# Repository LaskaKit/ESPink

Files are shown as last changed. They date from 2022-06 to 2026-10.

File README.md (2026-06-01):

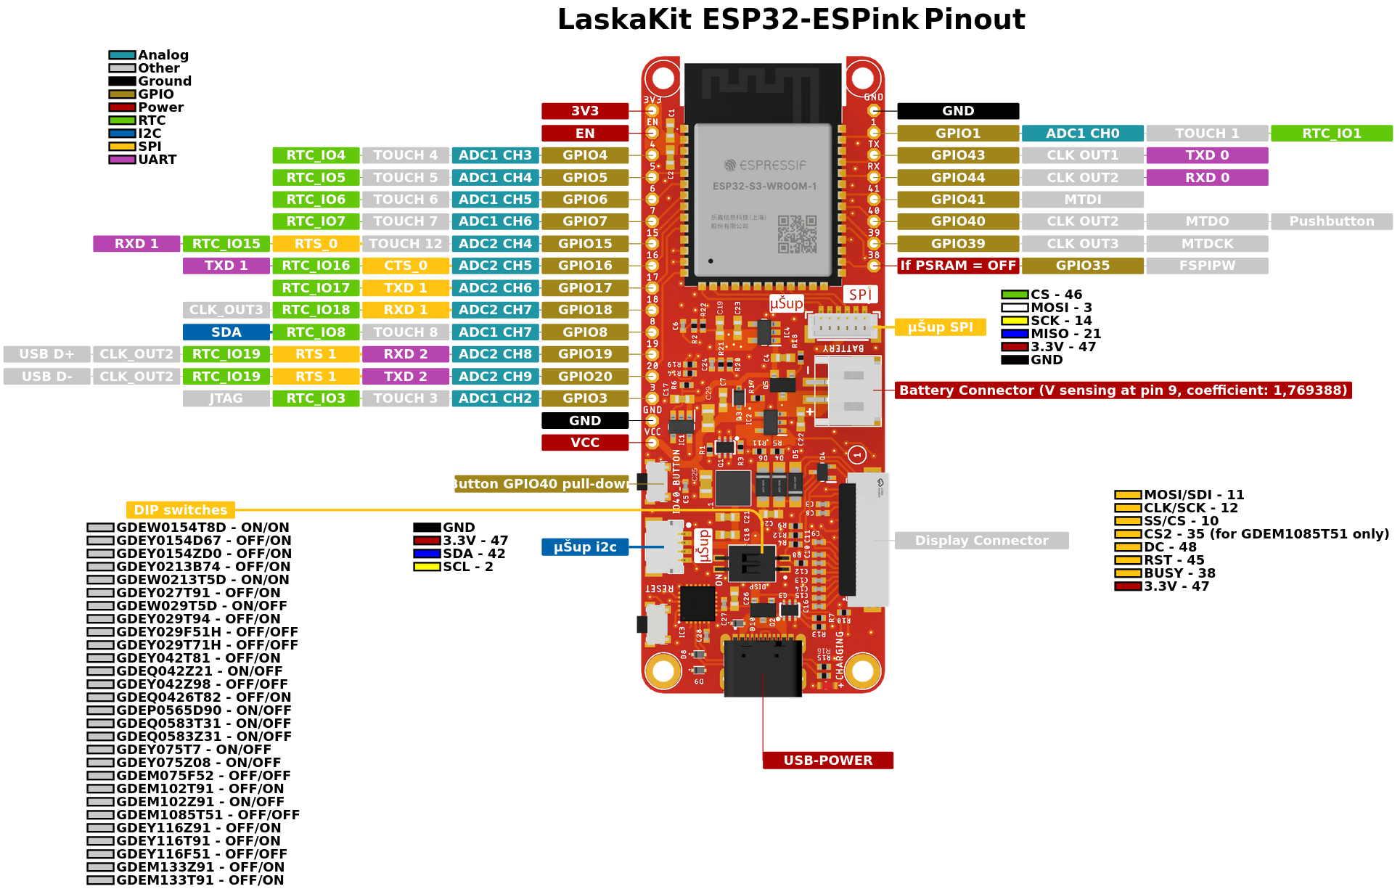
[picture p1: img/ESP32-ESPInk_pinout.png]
ESPink top


# ESPink - versatile and low power board with ESP32 for ePaper/eInk

[ePaper displays](https://www.laskakit.cz/e-ink/) are becoming more and more popular mainly thanks to their low power consumption and wide viewing angle. 
But which board you should use to control your E-Paper display? We designed a board to answer this very question: The ESPink, a small board focused on the lowest possible power consumption and with plenty of memory for large, complicated graphics. 
The ESPink is based on ESP32, one of the most popular and widely accepted development boards in the world. 

What makes this board so special? First of all, a dedicated connect onnector for connection of an ePaper/eInk display. EPaper displays consume very little power, but it is drawing current during sleep (a few uA). To achieve the lowest current, we added a transistor between power and input of ePaper. Thanks to this, the current through ePaper during the sleep is zero. This same tranzistor is also used to switch the µŠup I2C and µŠup SPI power.

One more feature is the built-in programmer, where we used really low power programmer.

The board is powered from [lipol battery](https://www.laskakit.cz/baterie-a-akumulatory/) which is chargered from USB-C, no longer micro USB. As is standard with our boards, we've included a voltage divider (coef. 1.769388) which allows you to measure the voltage of the connected battery.

The connection of sensors is simple and secure thanks to our I2C μŠup connector, which includes a mechanical lock and a pinout compatible with all sensors and boards made by laskakit.cz, in addition to Adafruit STEMMA and Sparkfun QWIIC boards.  
Examples of boards with the μŠup connector are [LaskaKit SHT40 Sensor of temperature and humidity](https://www.laskakit.cz/laskakit-sht40-senzor-teploty-a-vlhkosti-vzduchu/) and  [LaskaKit SCD41 Sensor CO2, temperature and humidity ](https://www.laskakit.cz/laskakit-scd41-senzor-co2--teploty-a-vlhkosti-vzduchu/).
We also added an SPI μŠup connector for adding more data-hungry devices, such as SD card readers. 

The ESP32 has a lot of available GPIO pins which we didn't use, which are accesible via solder pads, allowing you to connect any and all modules you can think of.

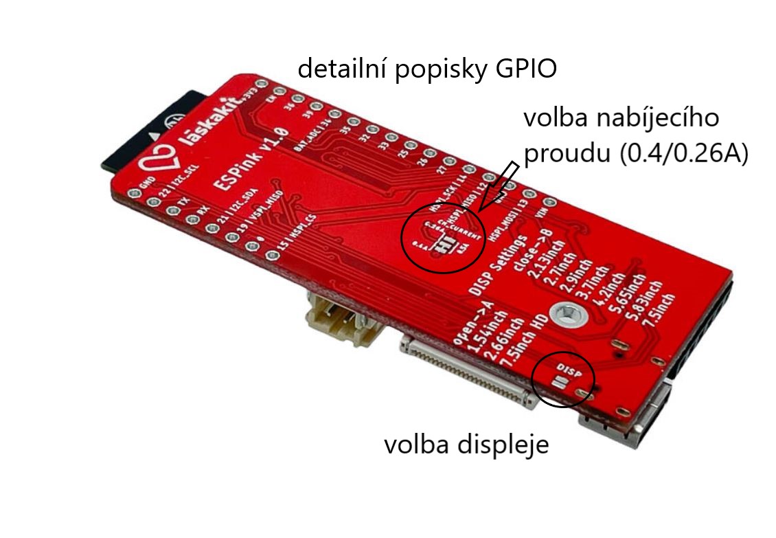
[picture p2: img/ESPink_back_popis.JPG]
ESPink top


The ESPink was precisly designed for low power, but also the labeled GPIO what we used on board. On the bottom side is solder bridge, which defines the charging current. By default it is set 400 mA, but you can choose 260 mA. Just cut the this track and put a drop of solder on the oposite side of solder bridge.

ESPink is available on https://www.laskakit.cz/laskakit-espink-esp32-e-paper-pcb-antenna/
We prepared example codes available here: https://github.com/LaskaKit/ESPink/tree/main/SW

## Pinout
### Board

| Function | Board Version 2.7 | Board Version 3.5 |
| --- |:---:|:---:|
| MOSI/SDI | 23 | 11 |
| CLK/SCK | 5 | 10 |
| CS2 | - | 35 |
| DC | 17 | 48 |
| RST | 16 | 45 |
| BUSY | 4 | 38 |
| Voltage divider | 34 | 9 |

### µŠup I2C

| Function | Board Version 2.7 | Board Version 3.5 |
| --- |:---:|:---:|
|SDA|21|42|
|SCL|22|2|

### µŠup SPI

| Function | Board Version 2.7 | Board Version 3.5 |
| --- |:---:|:---:|
|MOSI/SDI|13|3|
|MISO/SDO|12|21|
|SCK|14|14|
|CS|15|46|

### DIP Switch positions
| Display Name | Positions |
| --- | --- |
| GDEW0154T8D  | ON/ON |
| GDEY0154D67  | OFF/ON |
| GDEY0154ZD0  | OFF/ON |
| GDEY0213B74  | OFF/ON |
| GDEW0213T5D  | ON/ON |
| GDEY027T91 | OFF/ON |
| GDEW029T5D | OFF/OFF |
| GDEY029T94 | OFF/OFF |
| GDEY029F51H  | OFF/ON |
| GDEY029T71H  | ON/OFF |
| GDEY042T81 | OFF/ON |
| GDEQ042Z21 | ON/OFF |
| GDEY042Z98 | OFF/OFF |
| GDEQ0426T82  | OFF/ON |
| GDEP0565D90  | ON/OFF |
| GDEQ0583T31  | ON/OFF |  
| GDEQ0583Z31  | ON/OFF |
| GDEY075T7 | ON/OFF |
| GDEY075Z08 | ON/OFF |
| GDEM075F52 | OFF/OFF |
| GDEM102T91 | OFF/ON |
| GDEM102Z91 | OFF/ON |
| GDEM1085T51  | OFF/OFF |
| GDEY116Z91 | OFF/ON |
| GDEY116T91 | OFF/ON |
| GDEY116F51 | OFF/OFF |
| GDEM133Z91 | OFF/ON |
| GDEM133T91 | OFF/ON |

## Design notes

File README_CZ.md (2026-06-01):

ESPink top

# ESPink - univerzální a velmi úsporná deska s ESP32 pro ePaper

[ePaper displeje](https://www.laskakit.cz/e-ink/) nabírají neuřitelné popularity a není divu. Především velmi nízký odběr a široký pozorovací úhel dělá ePaper tak populárním. 
Ale čím tento displej řídit? Proto jsme navrhli ESPink. Velká paměť, nízký odběr, snadné připojení I2C čidel a velká komunita bastlířů okolo ESP32.

Na desce samozřejmě najdeš konektor pro ePaper displeje. Někdy nazvaný také Eink. Displej sám o sobě je velmi úsporný, ale stejně i mimo fázi přepisu odebírá nějaké ty uA. 
I takovému odběru jsme chtěli zamezit a tak jsme do napájení přidali tranzistor, který spíná nejen napájení E-Paper displeje, ale i µŠup I2C a µŠup SPI.

Nízká spotřeba je dosažena i tím, že jsme použili programátor, který je sám o sobě velmi úsporný a tak jeho osazení na desce nepřinese o mnoho vyšší spotřebu.

Deska může být napájena z [lipol akumulátoru](https://www.laskakit.cz/baterie-a-akumulatory/) a ten je nabíjen z USB-C konektoru. 
Samozřejmě můžeš měřit i napětí na akumulátoru díky integrovanému děliči napětí (koef. 1,769388).

Připojení čidel nebylo nikdy snažší a bezpečnější. Žádná nefungující čidla způsobená přepolováním. Díky našemu I2C μŠup konektoru, který obsahuje i zámek čidla jednoduše připojíš. 
Mezi taková čidla s μŠup konektorem patří [LaskaKit SHT40 Senzor teploty a vlhkosti vzduchu ](https://www.laskakit.cz/laskakit-sht40-senzor-teploty-a-vlhkosti-vzduchu/) nebo  [LaskaKit SCD41 Senzor CO2, teploty a vlhkosti vzduchu ](https://www.laskakit.cz/laskakit-scd41-senzor-co2--teploty-a-vlhkosti-vzduchu/).
Na desce je i SPI μŠup konektor, který může být použit například pro připojení naší desky nazvané microSD reader. 

K dispozici je i spousta GPIO, na které si můžeš zapájet, co budeš potřebovat.

ESPink top

Dali jsme si záležet i na takových detailech, jako jsou například označené GPIO, které deska využívá. Na zadní straně se ještě nachází pájecí most, který určuje nabíjecí proud. 
Ve vychozím nastavení je nastaveno 400mA. Pokud chceš nabíjet 260mA, je nutné proškrábnout most a zapájet jej na druhé straně. 

ESPink najdeš na našem e-shopu https://www.laskakit.cz/laskakit-espink-esp32-e-paper-pcb-antenna/
A několik vzorových kódu i na našem githubu https://github.com/LaskaKit/ESPink/tree/main/SW

## Pinout
### Deska

| Funkce | Verze Desky 2.7 | Verze Desky 3.5 |
| --- |:---:|:---:|
| MOSI/SDI | 23 | 11 |
| CLK/SCK | 5 | 10 |
| CS2 | - | 35 |
| DC | 17 | 48 |
| RST | 16 | 45 |
| BUSY | 4 | 38 |
| Dělič napětí | 34 | 9 |

### µŠup I2C

| Funkce | Verze Desky 2.7 | Verze Desky 3.5 |
| --- |:---:|:---:|
|SDA|21|42|
|SCL|22|2|

### µŠup SPI

| Funkce | Verze Desky 2.7 | Verze Desky 3.5 |
| --- |:---:|:---:|
|MOSI/SDI|13|3|
|MISO/SDO|12|21|
|SCK|14|14|
|CS|15|46|

### Pozice pro DIP přepínače
| Displej | Pozice |
| --- | --- |
| GDEW0154T8D  | ON/ON |
| GDEY0154D67  | OFF/ON |
| GDEY0154ZD0  | OFF/ON |
| GDEY0213B74  | OFF/ON |
| GDEW0213T5D  | ON/ON |
| GDEY027T91 | OFF/ON |
| GDEW029T5D | OFF/OFF |
| GDEY029T94 | OFF/OFF |
| GDEY029F51H  | OFF/ON |
| GDEY029T71H  | ON/OFF |
| GDEY042T81 | OFF/ON |
| GDEQ042Z21 | ON/OFF |
| GDEY042Z98 | OFF/OFF |
| GDEQ0426T82  | OFF/ON |
| GDEP0565D90  | ON/OFF |
| GDEQ0583T31  | ON/OFF |  
| GDEQ0583Z31  | ON/OFF |
| GDEY075T7 | ON/OFF |
| GDEY075Z08 | ON/OFF |
| GDEM075F52 | OFF/OFF |
| GDEM102T91 | OFF/ON |
| GDEM102Z91 | OFF/ON |
| GDEM1085T51  | OFF/OFF |
| GDEY116Z91 | OFF/ON |
| GDEY116T91 | OFF/ON |
| GDEY116F51 | OFF/OFF |
| GDEM133Z91 | OFF/ON |
| GDEM133T91 | OFF/ON |

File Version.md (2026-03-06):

### Version 3.6
- Jumper for Pervasive Displays added
- Fixed typo: IO35 on the top was marked 38
#### Version 3.5
- Epaper BUSY pin changed from IO36 to IO38
- Epaper CS2 pin changed from IO35 to IO18
- µŠup SPI MOSI pin changed from IO37 to IO3
- Fuel gauge replaced by ADC
#### Version 3.4
- Reset button and ESP32 moved about 1.5mm
#### Version 3.3
- Changed pull-ups R14, R19 +3.3V to VSENSOR, added fuel gauge, new power part
#### Version 3.1
- Updated, more configurable driver schématic for display, based on displays datasheet and adapters from Good Display.
- Simplified power switching for display.
- Switching Battery ADC on GPIO09
#### Version 2.7
- Layout optimization for power delivery and  added 47uF capacitor to for ESP
#### Version 2.6
- Resistor R12 changed to 2.55 Ohm
#### Version 2.5
- Programming chip (CH9102) added. Still about 10µA in deep sleep ;)
- New µŠUP SPI connector (need to be powered by pin IO02)
- Separated LDO with Enable pin IO02 for uSup connector, 500mA max on 3.3V
#### Version 1.3
- ADC jumper moved and default closed | Propojka ADC se přesunula a ve výchozím nastavení uzavřena
- Error fixed, pins 13 and GND were swapped | Opravené chybá popisu, prohození pinů 13 a GND
#### Version 1.2
Adjusted resistor values in the resistance divider to 1M/1.3M, ADC max. input voltage stays the same.| Upraveny hodnoty rezistorů v odporovém děliči na 1M/1.3M, ADC max. vstupní napětí zůstává stejné.
#### Version 1.1
- Minor update, description, shape  | Malé změny, popis, tvar...
#### Version 1.0
- Initial | Počáteční

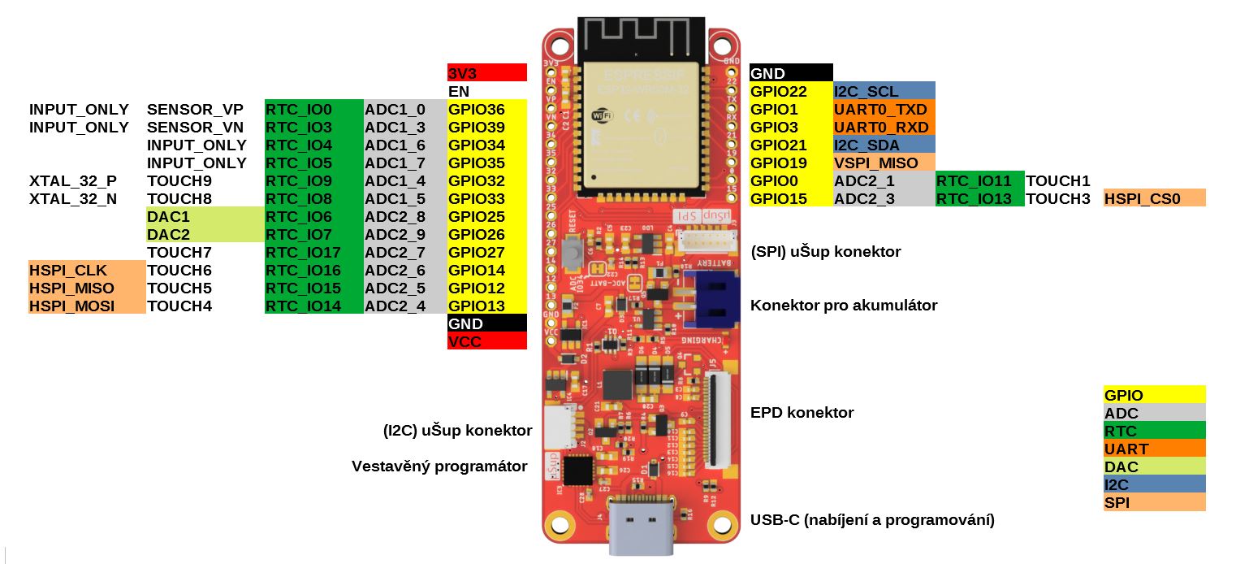
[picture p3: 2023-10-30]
img/ESPink_pinout_top.JPG

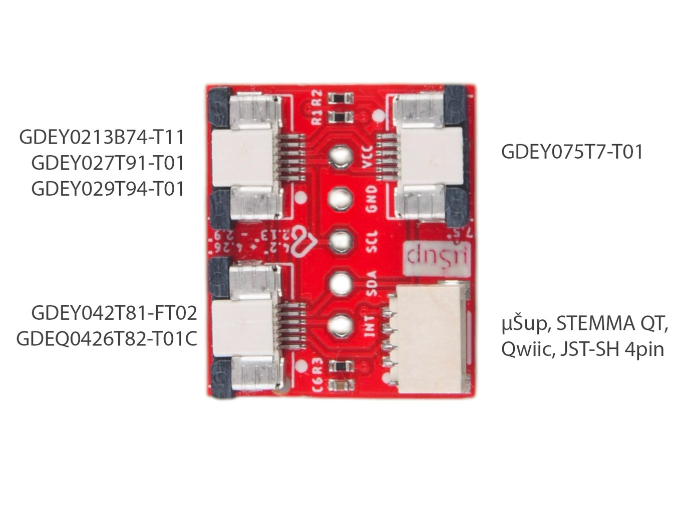
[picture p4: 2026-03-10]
img/LaskaKit-e-paper-touch-adapter-desc.jpg

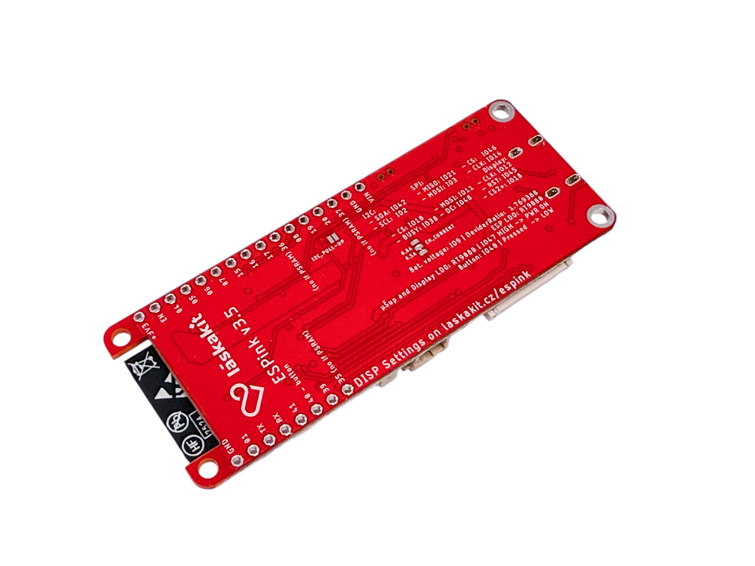
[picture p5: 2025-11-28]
img/LaskaKit-espink-esp32-e-paper-pcb-antenna-3.jpg

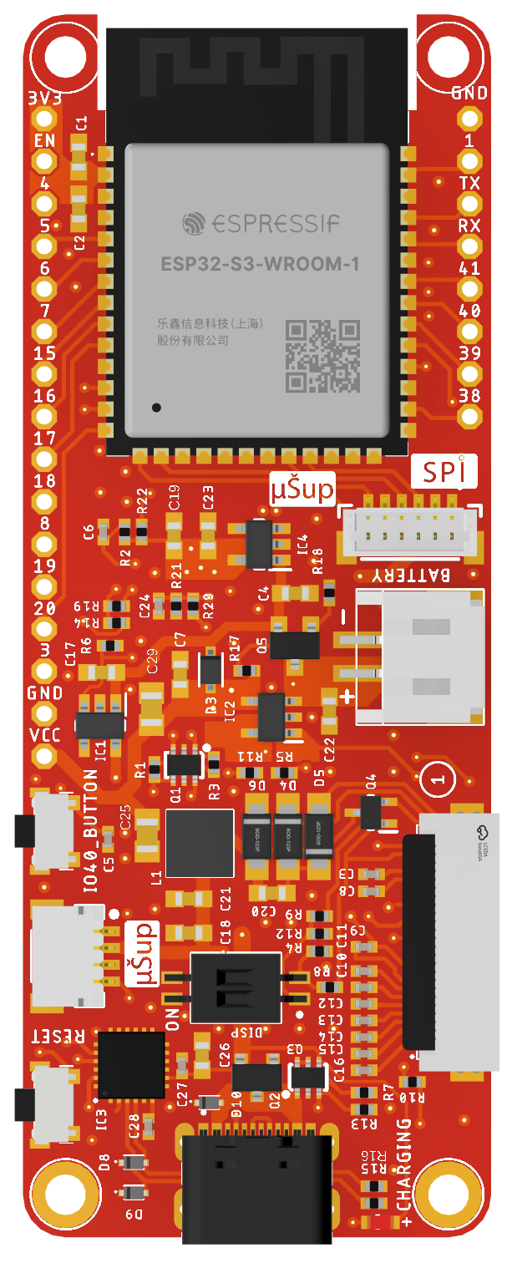
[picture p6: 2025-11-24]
img/ESPink_v3_pinout.png

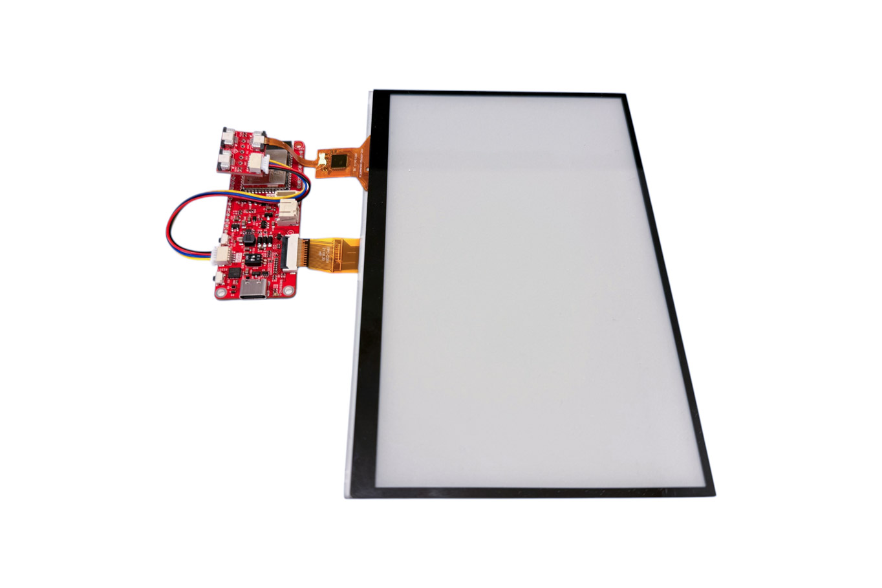
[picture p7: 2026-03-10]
img/LaskaKit-e-paper-touch-adapter-d.jpg

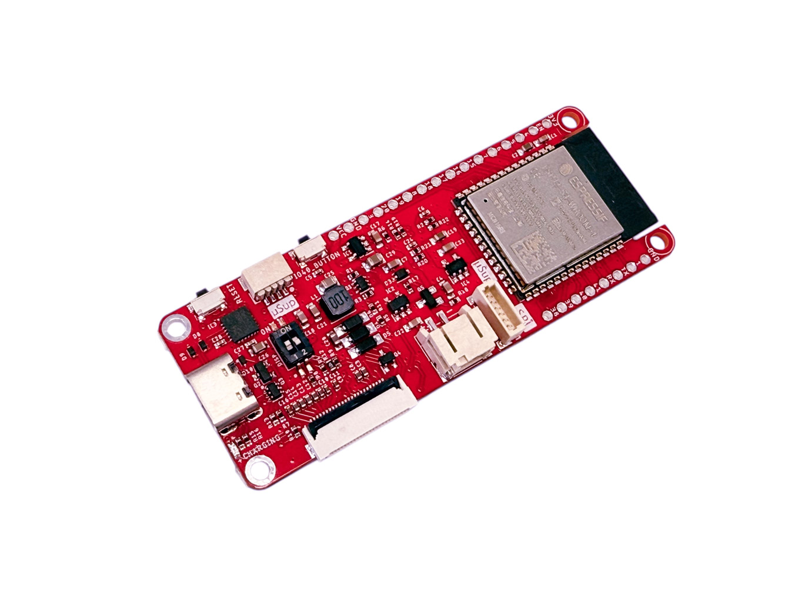
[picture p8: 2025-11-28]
img/LaskaKit-espink-esp32-e-paper-pcb-antenna-1.jpg

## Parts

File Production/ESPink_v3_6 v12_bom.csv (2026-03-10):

Comment | Designator | Footprint | LCSC Part #
0.47R | R9 | R0402 | C723356
1.3M | R21 | R0402
1M | R4 R20 | R0402
1k | R5 | R0402
1uF/50V | C9 C10 C11 C16 | C0402
2.55R | R12 | R0402 | C477655
3.3k | R10 | R0402
4.7k | R14 R19 | R0402
4.7uF/25V | C3 C8 C12 C13 C14 C15 | C0402
4.7uF/25V | C20 | C0603
5.1k | R15 R16 | R0402
10k | R1 R2 R3 R6 R8 R17 R22 | R0402
10uF/16V | C4 C7 C17 C18 C22 C23 | C0603
10uF/25V | C21 | C0603
10uH/1A | L1 | SMNR4020 | C497803
22uF/16V | C26 | C0603
47k | R7 R13 | R0402
47uF | C2 C19 | C0603 | C178330
47uF | C25 C29 | C0805
100k | R18 | R0402
100n | C27 C28 | C0402
100nF | C1 | C0603
100nF | C5 C6 C24 | C0402
180 | R11 | R0402
AFC24-S24FIC-00 | J5 | FFC2B2824G | C262292
AO3401 | Q5 | SOT23
BAT60B | D3 | SOD323-R
CH9102F | IC3 | QFN24-4X4
DMG2305UX | Q2 | MICRO3 | C144153
DSHP02TS-S | DISP | DSHP02TSS | C319052
EN button | RESET | 1TS003B16003500A | C255808
ESP32-S3-WROOM-1-N16R8 | IC5 | ESP32S3WROOM1N16
JST-PH-2_SMD/90SMD | BATTERY | S2B-PH-SM4 | C47647
JST-SH-4P | J2 | 1X04_1MM_RA
LESD5D5.0CT1G | D8 D9 D10 | LESD5D50CT1G
MBR0530 | D4 D5 D6 | SOD123-F
MMDT3904 | Q1 | SC70-6 | C268586
MMDT5401 | Q3 | SC70-6 | C54540
RED | CHARGING | CHIP-LED0603 | C241893
RT9080-33GJ5 | IC1 IC4 | SOT94P280X100-5N
Si1308EDL | Q4 | SOT65P210X110-3N | C469327
TP4054 | IC2 | SOT-23-5 | C382138
USB-C_GT-USB-7010B | J4 | G-SWITCH_GT-USB-7010B | C2837092
USUP_SPI_CONNECTOR_VERT | J3 | 1X06_1MM_RA_VERT | C145963
button | IO40_BUTTON | 1TS003B16003500A | C255808
JUMPER-SMT_2_NO_NO-SILK | I2C_PULL-UP JP3 | SMT-JUMPER_2_NO_NO-SILK
JUMPER-SMT_3_1-NC_TRACE_NO-SILK | CH_CURRENT | SMT-JUMPER_3_1-NC_TRACE_NO-SILK

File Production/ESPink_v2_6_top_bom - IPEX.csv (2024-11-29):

Comment | Designator | Footprint | LCSC Part #
0.47R | R9 | R0402
1.3M | R14 | R0402
1M | R13 R19 | R0402
1k | R7 | R0402
1k65 | R5 | R0402
1uF | C3 | C0402K
1uF | C7 | C0603
1uF | C8 C9 C10 C11 C12 C13 C14 C15 C16 | C0402K
2.55R | R12 | R0402 | C477655
3k3 | R11 | R0402
4.7uF | C5 C20 | C0603 | C92758
5.1k | R15 R16 | R0402
AO3400 | Q4 | SOT23-3 | C20917
10k | R1 R2 R3 R8 R17 R20 | R0402
10uF | C21 | C0603
22uF | C4 C17 C18 C23 C26 | C0603
47uF | C2 | C0603 | C730416
68uH | L1 | SMNR4020 | C135265
100k | R4 R6 R18 | R0402
100n | C27 C28 | C0402
100nF | C1 | C0603
100nF | C6 | C0402K
100nF | C22 | C0402
330 | R10 | R0402
AFC24-S24FIC-00 | J5 | FFC2B2824G | C2856831
AO3401 | Q3 Q5 | SOT23
AP2191WG-7 | IC1 | SOT25 | C141321
BAT60B | D1 D2 D3 | SOD323-R
CH9102F | IC3 | QFN24-4X4
EN button | RESET | TS1088R02026 | C455280
ESP32-WROOM | ESP32 | ESP32WROOM32D | C701346
HT7833 | LDO | SOT23-5 | C164106
JST-PH-2/90SMD | BATTERY | S2B-PH-SM4 | C47647
JST-SH-4P | J2 | 1X04_1MM_RA | C145956
MBR0530 | D4 D5 D6 | SOD123-F
ME6211C33M5G | IC4 | SOT23-5
MMDT3904 | Q1 | SC70-6 | C268586
POLIFUSE0500805L | F1 F2 | 0805L | C66452
RED | CHARGING | CHIP-LED0603 | C2286
S8050 | Q2 | SOT23-BEC
TP4054 | U1 | SOT-23-5 | C32574
USB-C_2-16PIN | J4 | USBC_USB-C-16P-5 | C2837092
USUP_SPI_CONNECTOR_VERT | J3 | 1X06_1MM_RA_VERT | C495540

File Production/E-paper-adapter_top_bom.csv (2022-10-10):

Comment | Designator | Footprint | LCSC Part #
AFC24-S24FIC-00 | J1 J2 | FFC2B2824G | C262292

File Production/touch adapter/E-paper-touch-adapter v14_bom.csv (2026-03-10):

Comment | Designator | Footprint | LCSC Part #
4.7k | R1 R2 | R0402
10k | R3 | R0402
100nF | C6 | C0402
AFC07-S06ECA-00 | U$1 U$2 U$4 | 6PIN_TOUCH
JST-SH_4P/90 | J1 | JST-SH_4P/90 | C7430446

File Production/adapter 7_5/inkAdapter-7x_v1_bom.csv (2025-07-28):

Comment | Designator | Footprint | LCSC Part #
100nF | C19 | C0402
AFC24-S24FIC-00 | J1 | FFC2B2824G | C262292
GDEM075XXX | U$4 | GDEM075XXX
JST-SH-4P | J4 | 1X04_1MM_RA
SHT40 | SHT40 | SHT40

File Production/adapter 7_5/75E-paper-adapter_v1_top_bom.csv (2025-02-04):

Comment | Designator | Footprint | LCSC Part #
AFC24-S24FIC-00 | J1 | FFC2B2824G | C262292
GDEM075XXX | U$4 | GDEM075XXX

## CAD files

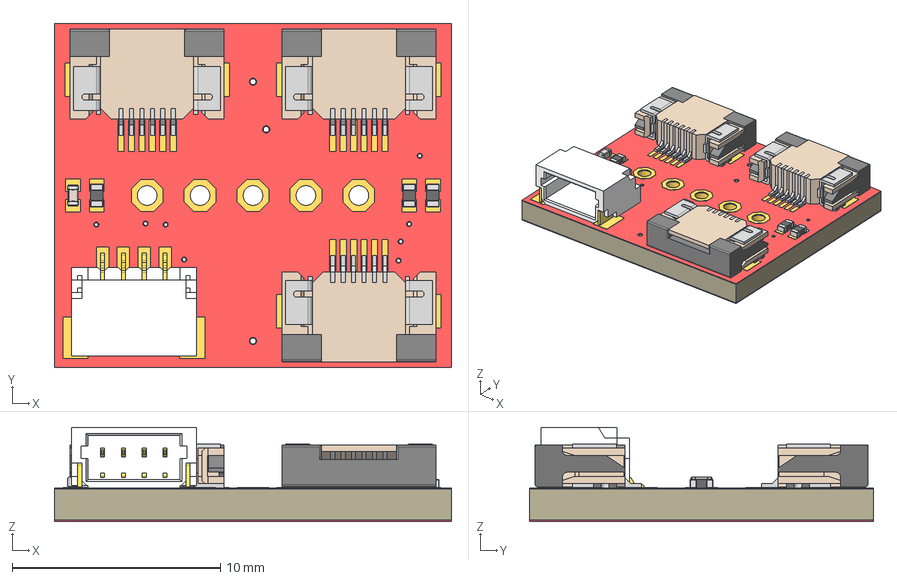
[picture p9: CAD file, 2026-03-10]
3D/E-paper-touch-adapter.step
19.1 x 16.5 x 4.52 mm
Board
1-copper
16-copper
1-soldermask
16-soldermask
Pin1
Pin2
CeramicBody
LASKAKIT_HEART_3MM
LASKKIT_10MM_SILKSCREEN
USUP_SILKSCREEN
1X04_1MM_RA
R0402 x 3
6871xx14022_PIN x 18
6871xx14022_Patte x 3
6871xx14022_Patte_2 x 3
68710614022_CAP x 3

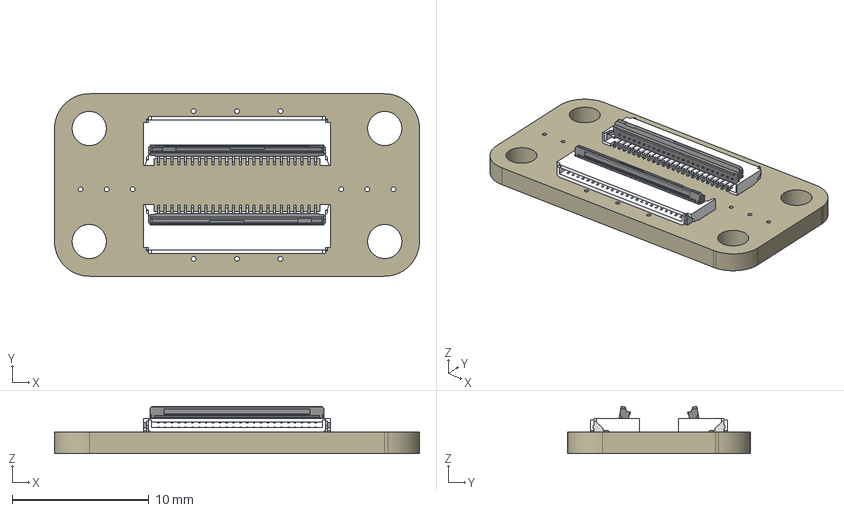
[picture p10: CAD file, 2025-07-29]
3D/E-paper-adapter.step
26.7 x 13.3 x 3.44 mm
Board
LASKAKIT_HEART_4MM
LASKKIT_20MM_SILKSCREEN
FFC2B2824G x 2

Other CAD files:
3D/E-paper-adapter.f3d
3D/E-paper-touch-adapter.f3d

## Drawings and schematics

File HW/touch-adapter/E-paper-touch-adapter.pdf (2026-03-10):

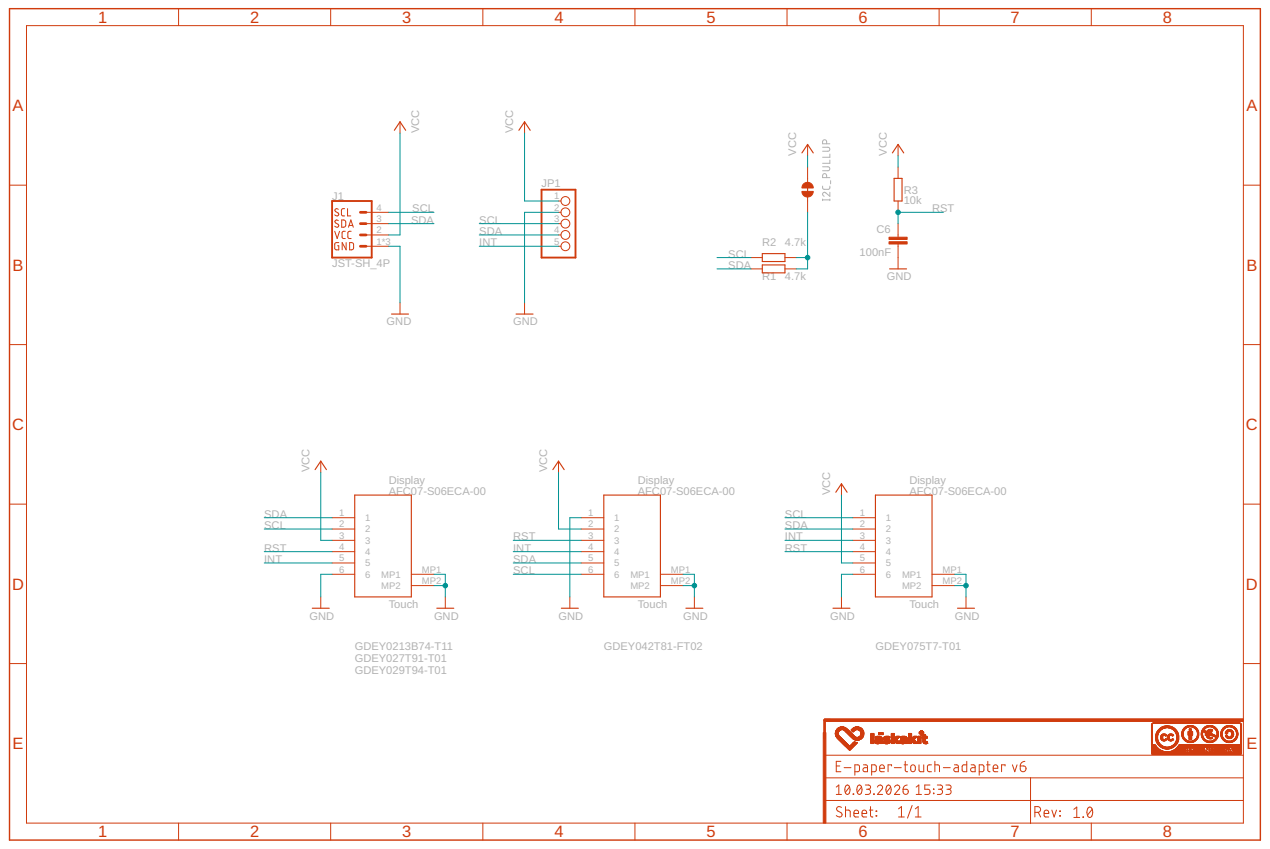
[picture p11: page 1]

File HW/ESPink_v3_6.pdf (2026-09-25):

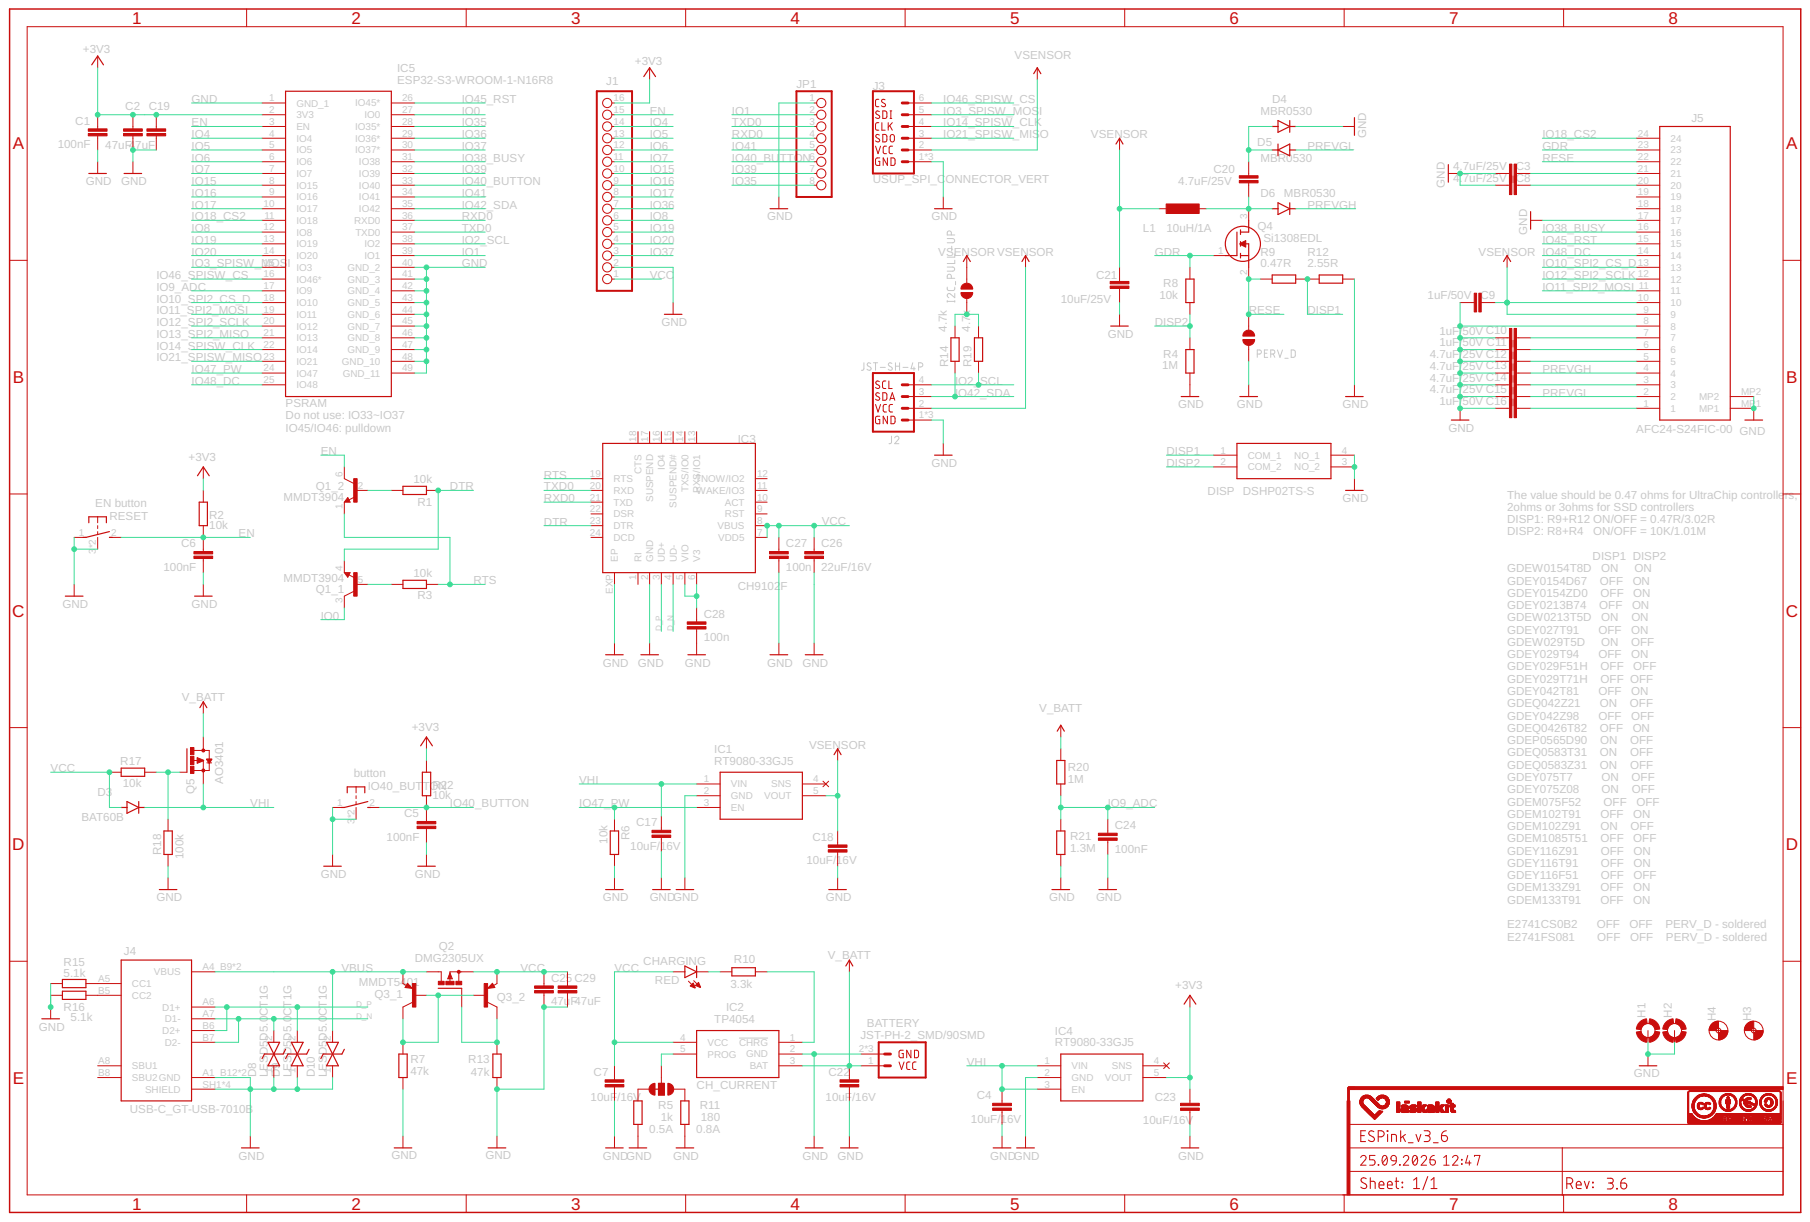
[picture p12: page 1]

The value should be 0.47 ohms for UltraChip controllers, 2ohms or 3ohms for SSD controllers DISP1: R9+R12 ON/OFF = 0.47R/3.02R

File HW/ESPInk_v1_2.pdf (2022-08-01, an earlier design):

# 1uF GND

## 8 JP1

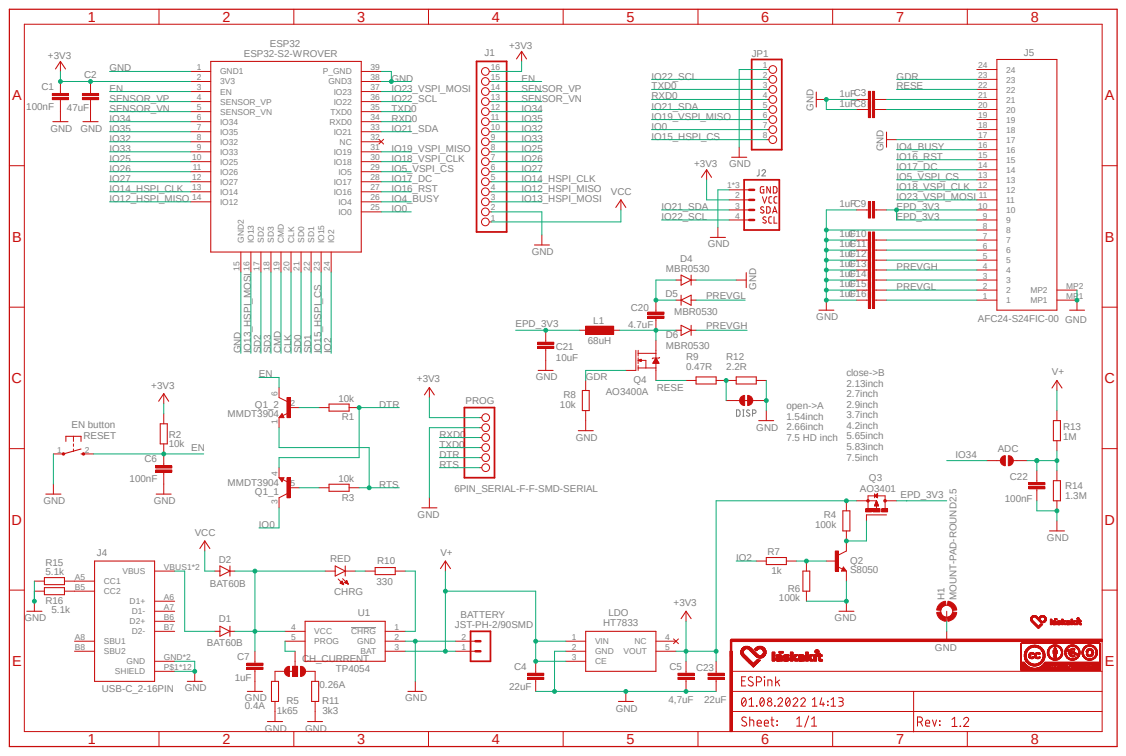
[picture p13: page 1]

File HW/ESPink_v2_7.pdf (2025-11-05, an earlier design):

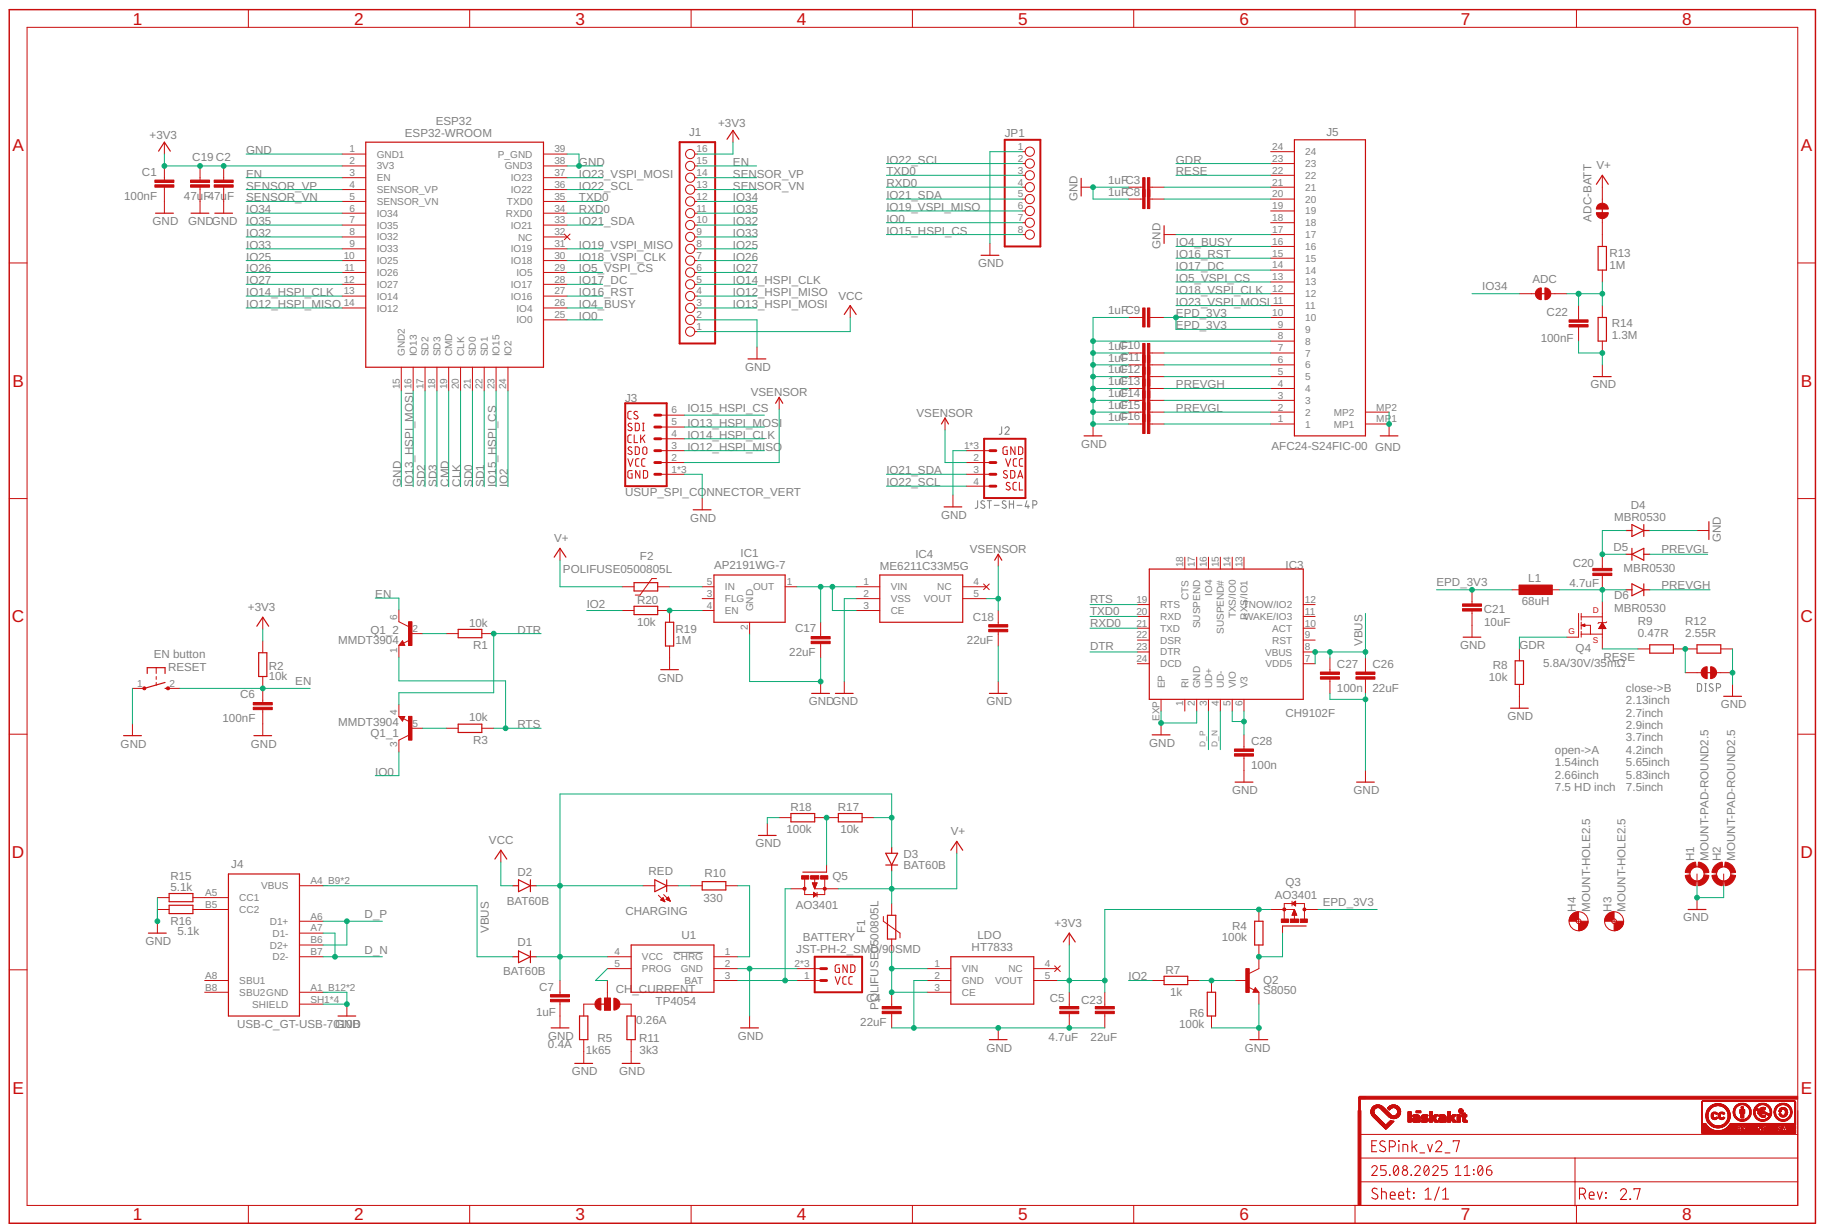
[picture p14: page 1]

1uF | 6
1uF | 5
1uF | PREVGH 4
1uF | 3
1uF | PREVGL 2

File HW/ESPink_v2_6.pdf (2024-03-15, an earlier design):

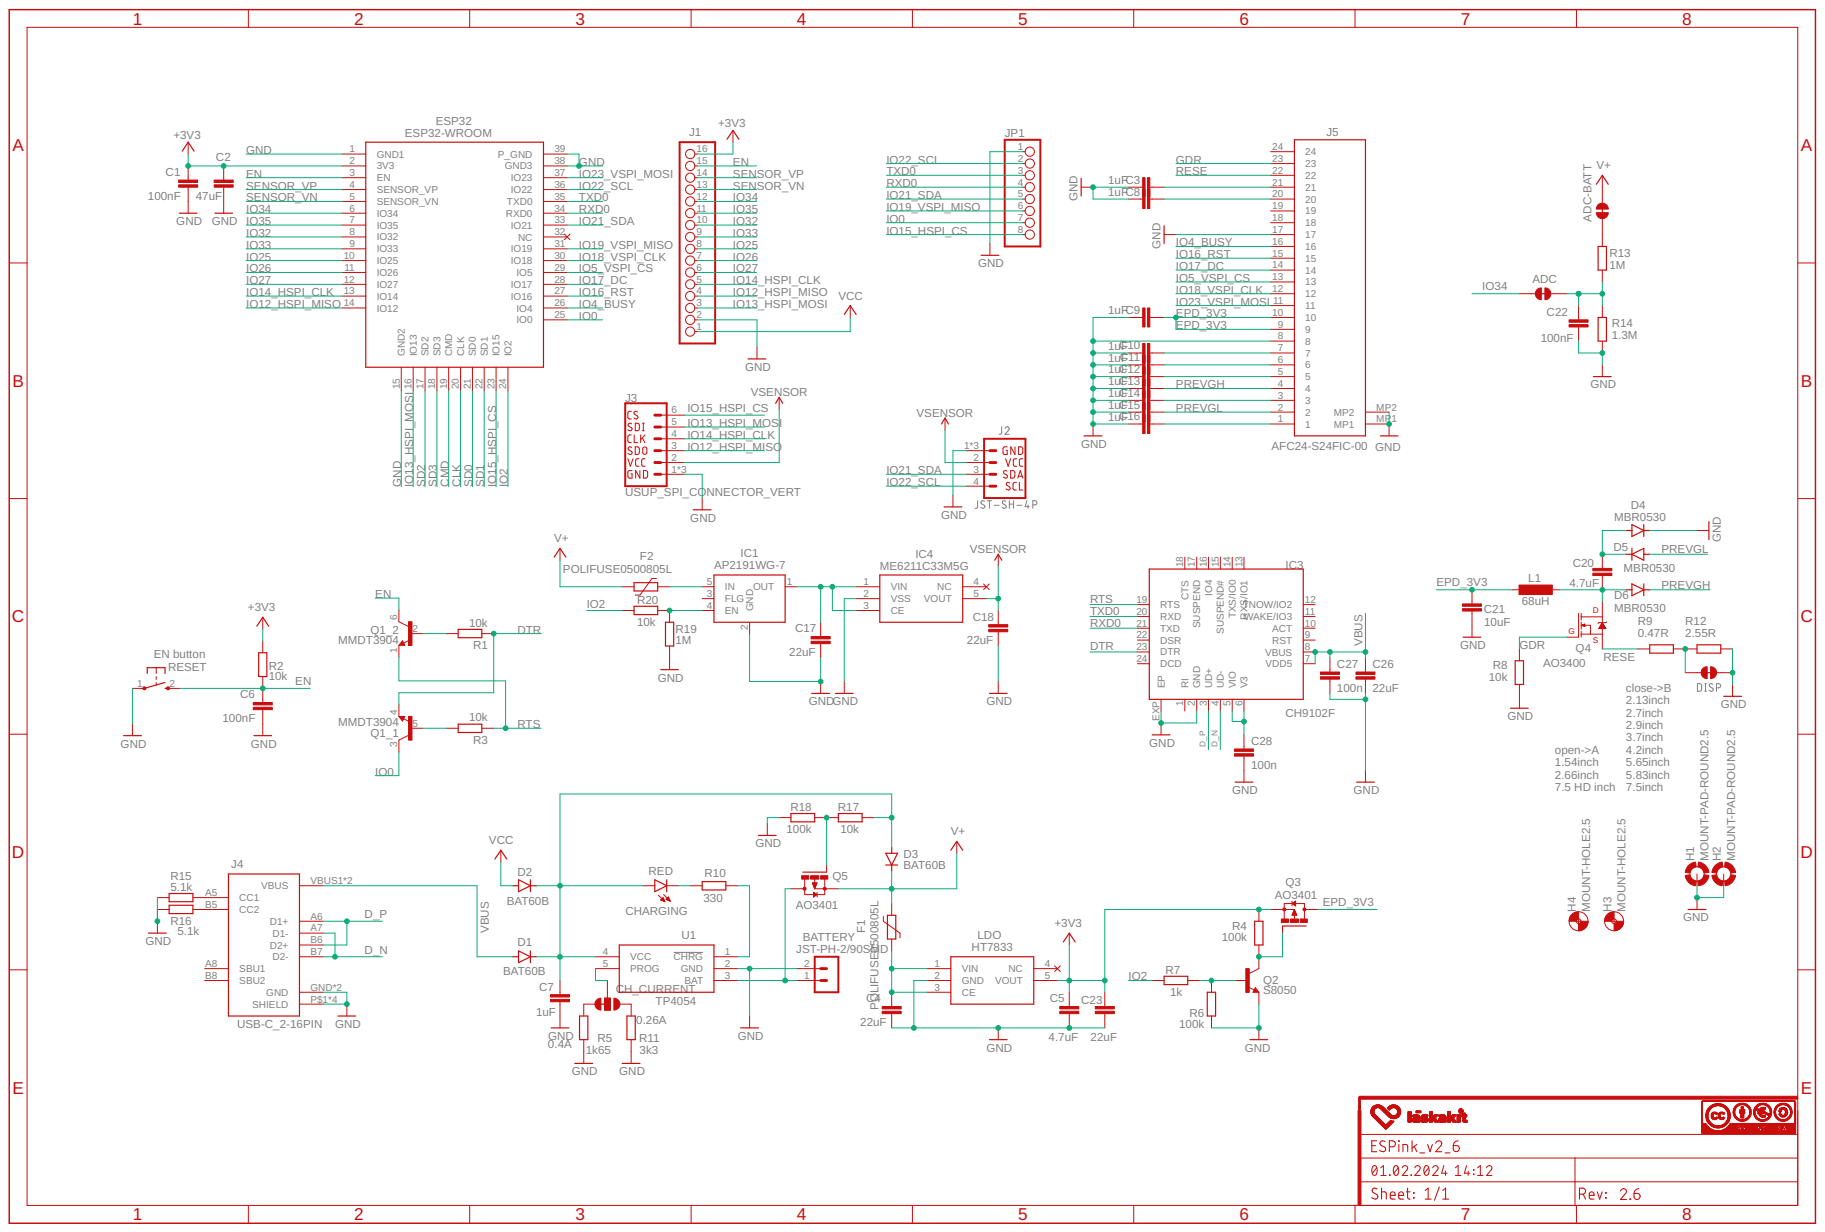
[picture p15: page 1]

1uF | 6
1uF | 5
1uF | PREVGH 4
1uF | 3
1uF | PREVGL 2

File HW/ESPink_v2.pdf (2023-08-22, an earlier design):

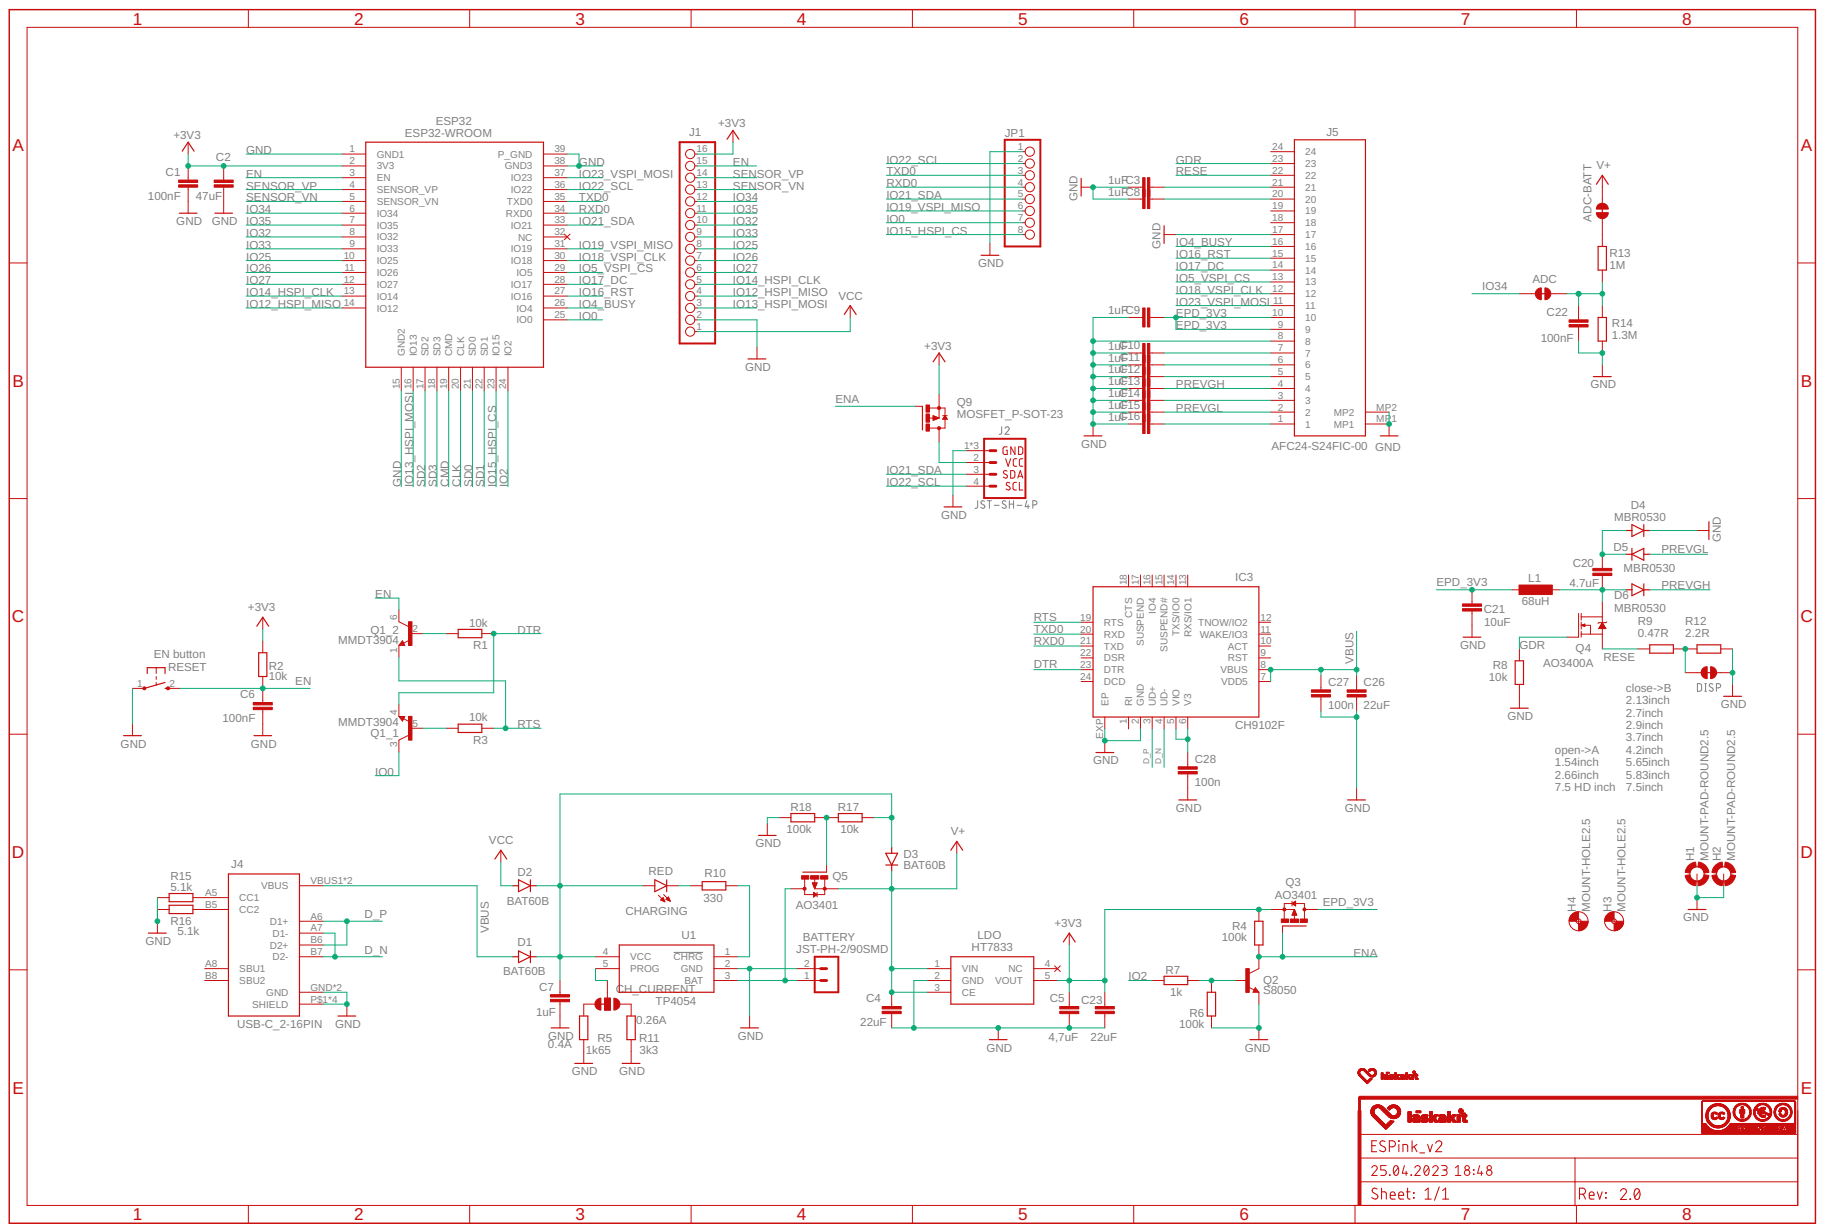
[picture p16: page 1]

1uF | 6
1uF | 5
1uF | PREVGH 4
1uF | 3
1uF | PREVGL 2
1uF | 1

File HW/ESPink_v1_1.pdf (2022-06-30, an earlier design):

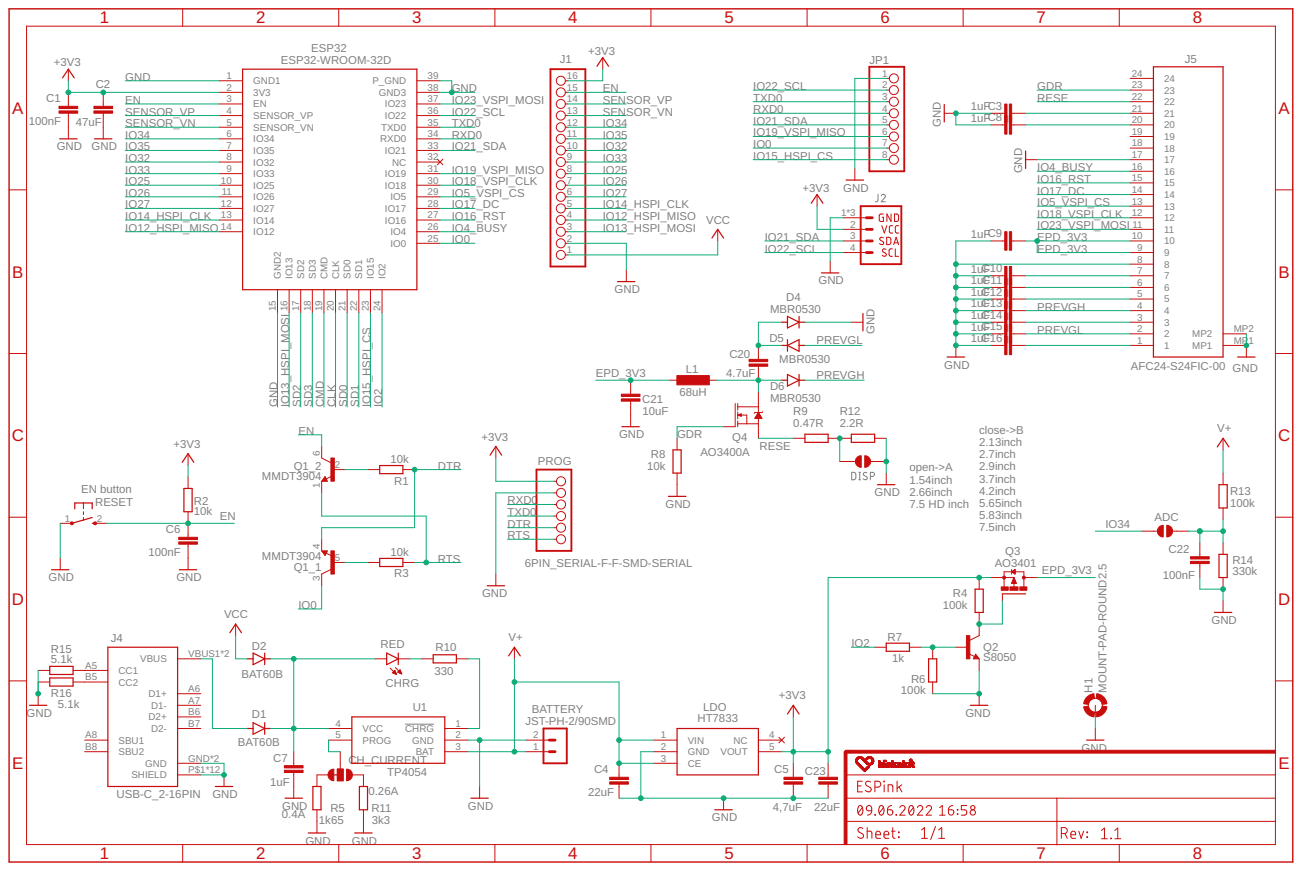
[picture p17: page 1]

1uF C10 | 7
1uF C11 | 6
1uF C12 | 5
1uF C13 | PREVGH 4
1uF C14 | 3

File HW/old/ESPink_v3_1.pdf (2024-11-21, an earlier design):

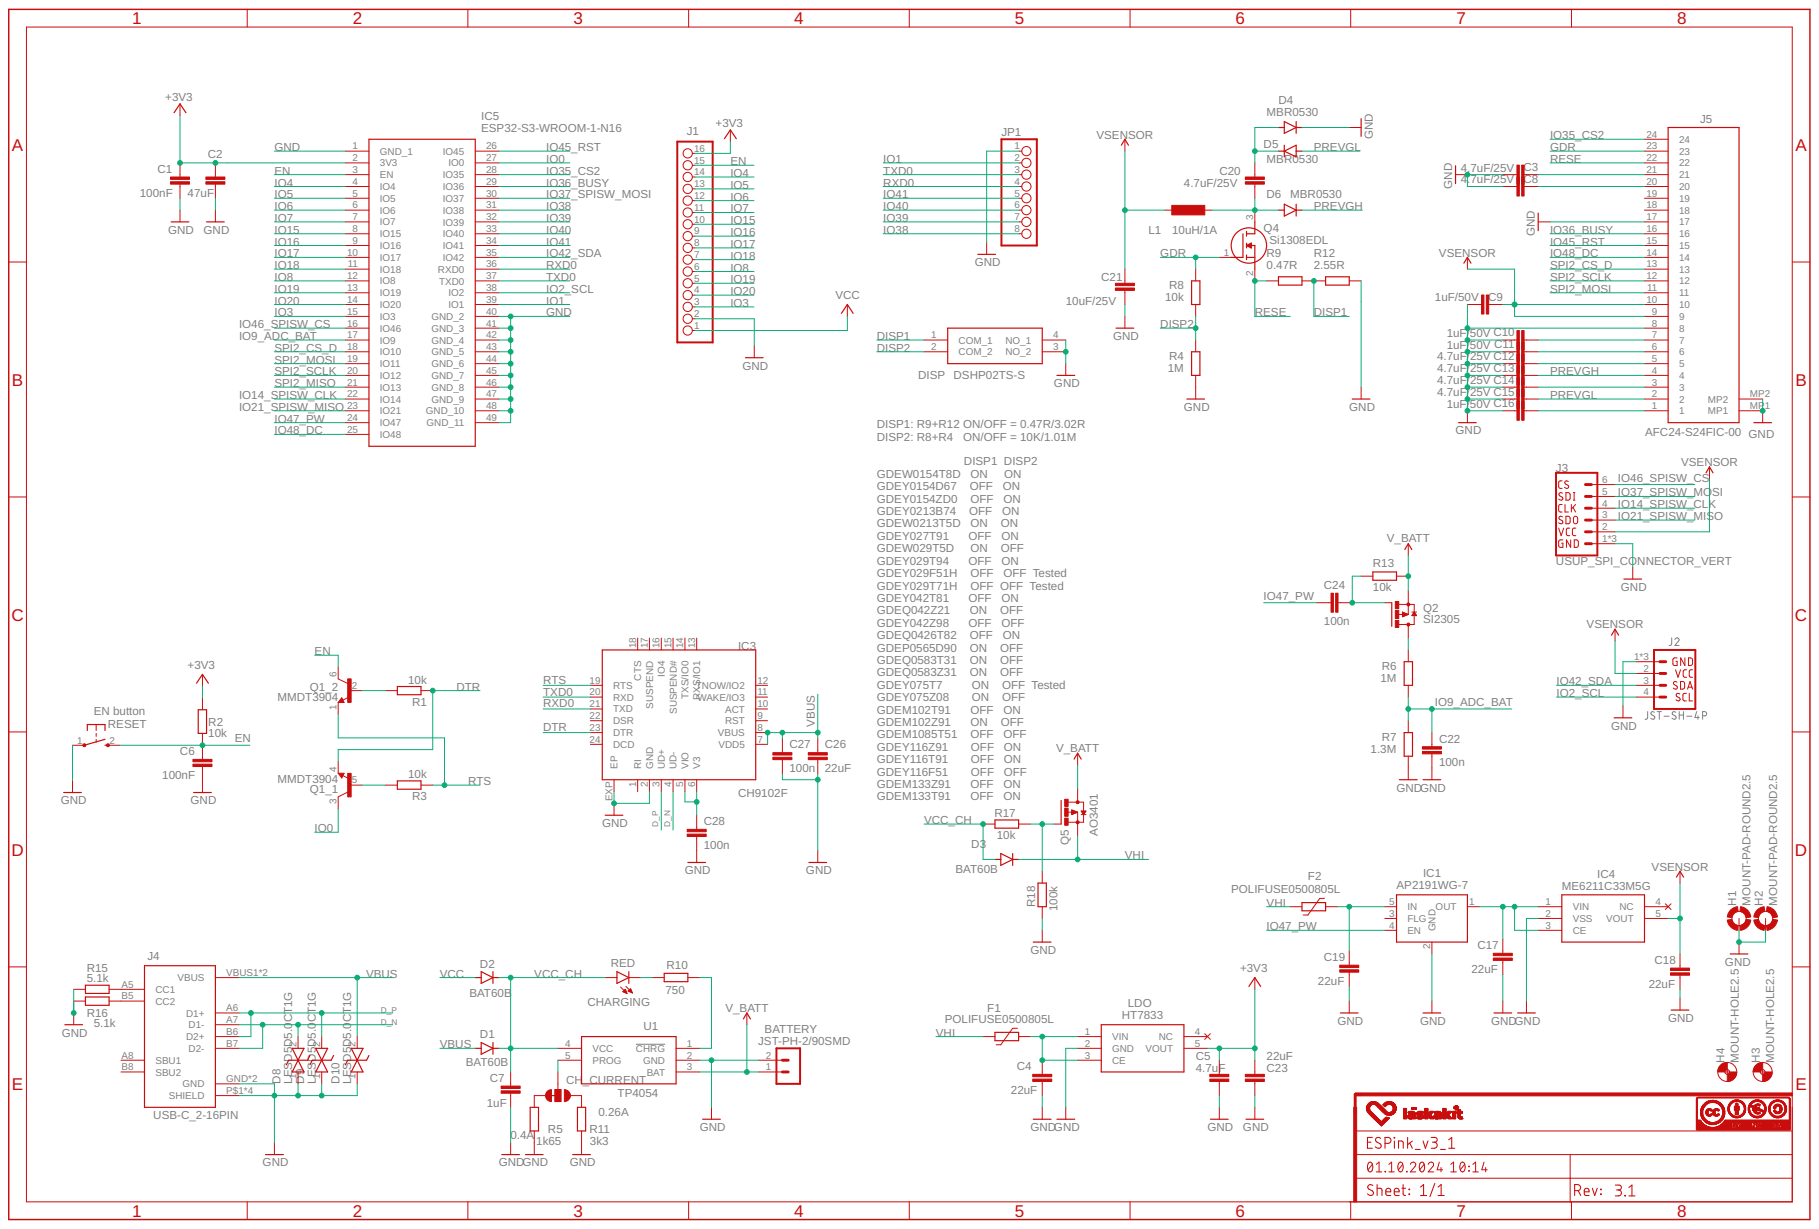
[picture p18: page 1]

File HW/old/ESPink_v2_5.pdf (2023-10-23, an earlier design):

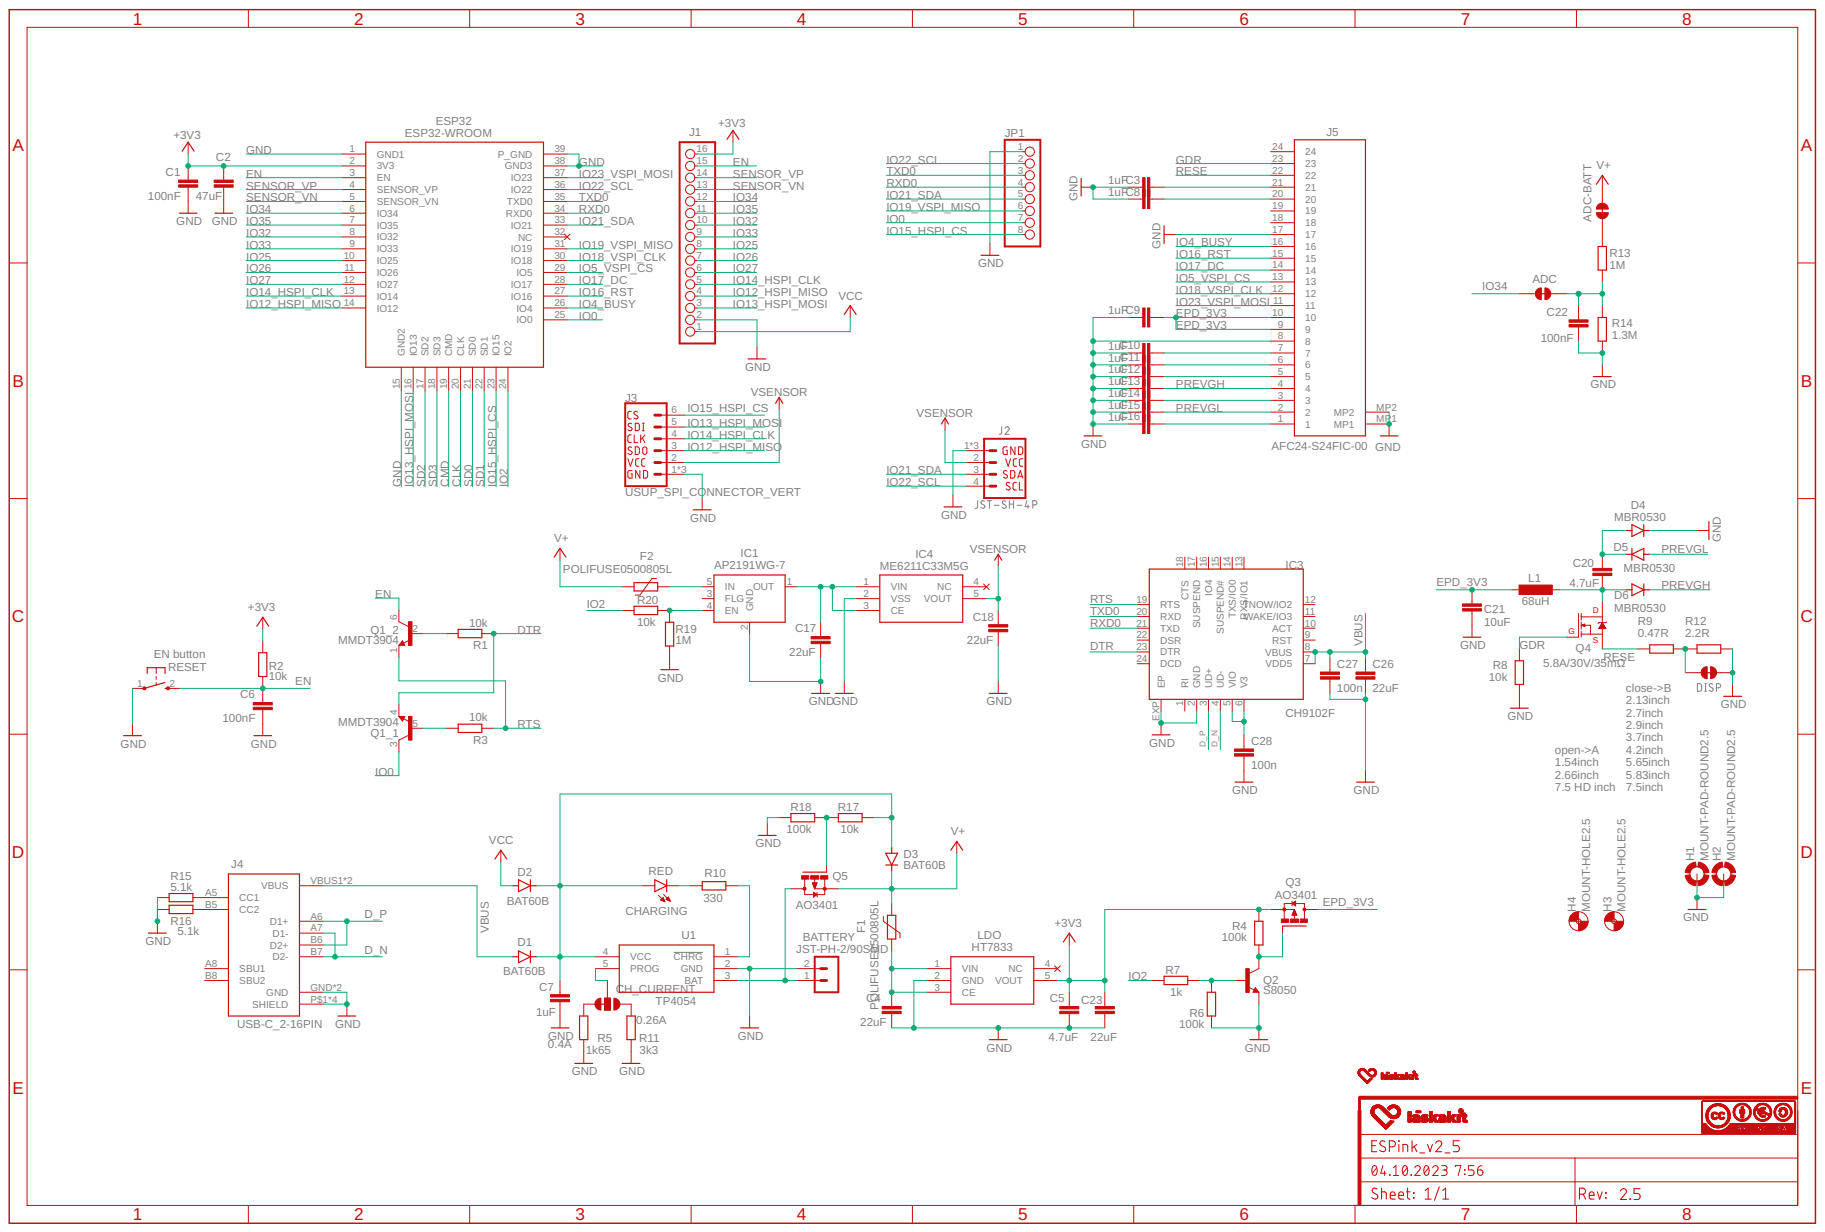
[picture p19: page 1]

1uF | 6
1uF | 5
1uF | PREVGH 4
1uF | 3
1uF | PREVGL 2

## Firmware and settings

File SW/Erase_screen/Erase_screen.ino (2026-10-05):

/*
* Example code for display erasing
*
* Board:   LaskaKit ESPink ESP32 e-Paper   https://www.laskakit.cz/laskakit-espink-esp32-e-paper-pcb-antenna/
* Libraries:
* EPD library: https://github.com/ZinggJM/GxEPD2
*
* made by laskakit (c) 2024
*/
 
#include <WiFi.h>
#include <GxEPD2_BW.h>
#include <GxEPD2_BW_SHM.h>
#include <GxEPD2_3C.h>
#include <GxEPD2_4C.h>
#include <GxEPD2_7C.h>
#include "SPI.h"


//#define ESPink_V2     //for version v2.6 and earlier
#define ESPink_V3     //for version v3.0 and above

#ifdef ESPink_V2
  //MOSI/SDI    23
  //CLK/SCK     18
  //SS/CS       5
  #define DC    17 
  #define RST   16  
  #define BUSY  4 
  #define POWER 2
#else ESPink_V3
  //MOSI/SDI    11
  //CLK/SCK     12
  //SS/CS       10
  #define CS2   35 // For GDEM1085T51 Only
  #define DC    48 
  #define RST   45  
  #define BUSY  38 
  #define POWER 47
#endif


/*------------------------  Define EPD driver - uncomment the used one  -----------------------------*/

//BW
//GxEPD2_BW<GxEPD2_154_D67, GxEPD2_154_D67::HEIGHT> display(GxEPD2_154_D67(SS, DC, RST, BUSY)); // 1.54" b/w
//GxEPD2_BW<GxEPD2_154_M10, GxEPD2_154_M10::HEIGHT> display(GxEPD2_154_M10(SS, DC, RST, BUSY)); // 1.54" b/w DES
///GxEPD2_BW<GxEPD2_154_T8, GxEPD2_154_T8::HEIGHT> display(GxEPD2_154_T8(SS, DC, RST, BUSY)); // GDEW0154T8D, GDEW0154T8  152x152, UC8151 (IL0373)
//GxEPD2_BW<GxEPD2_213_B74, GxEPD2_213_B74::HEIGHT> display(GxEPD2_213_B74(SS, DC, RST, BUSY)); // 2.13" b/w
//GxEPD2_BW<GxEPD2_213_M21, GxEPD2_213_M21::HEIGHT> display(GxEPD2_213_M21(SS, DC, RST, BUSY)); // 2.13" b/w DES
//GxEPD2_BW<GxEPD2_270, GxEPD2_270::HEIGHT> display(GxEPD2_270(SS, DC, RST, BUSY)); // GDEW027W3 176x264, EK79652 (IL91874)
//GxEPD2_BW<GxEPD2_290_GDEY029T71H, GxEPD2_290_GDEY029T71H::HEIGHT> display(GxEPD2_290_GDEY029T71H(SS, DC, RST, BUSY)); // GDEY029T71H 168x384, SSD1685, (FPC-H004 22.03.24)
//GxEPD2_BW<GxEPD2_420, GxEPD2_420::HEIGHT> display(GxEPD2_420(SS, DC, RST, BUSY)); // GDEW042T2 400x300, UC8176 (IL0398)
//GxEPD2_BW<GxEPD2_420_GDEY042T81, GxEPD2_420_GDEY042T81::HEIGHT> display(GxEPD2_420_GDEY042T81(SS, DC, RST, BUSY)); // GDEY042T81, 400x300, SSD1683 (no inking)
//GxEPD2_BW<GxEPD2_426_GDEQ0426T82, GxEPD2_426_GDEQ0426T82::HEIGHT> display(GxEPD2_426_GDEQ0426T82(SS, DC, RST, BUSY)); // GDEQ0426T82 480x800, SSD1677 (P426010-MF1-A)
GxEPD2_BW_SHM<GxEPD2_576_GDEH0576T81, GxEPD2_576_GDEH0576T81::HEIGHT / 2> display(GxEPD2_576_GDEH0576T81(SS, DC, RST, BUSY)); // GDEH0576T81 920x680, SSD2677
//GxEPD2_BW<GxEPD2_750_T7, GxEPD2_750_T7::HEIGHT> display(GxEPD2_750_T7(SS, DC, RST, BUSY)); // 7.5" b/w 800x480
//GxEPD2_BW < GxEPD2_1020_GDEM102T91, GxEPD2_1020_GDEM102T91::HEIGHT / 2> display(GxEPD2_1020_GDEM102T91(SS, DC, RST, BUSY)); // GDEM102T91 960x640, SSD1677, (FPC7705 REV.b)
//GxEPD2_BW < GxEPD2_1085_GDEM1085T51, GxEPD2_1085_GDEM1085T51::HEIGHT / 2> display(GxEPD2_1085_GDEM1085T51(SS, DC, RST, BUSY, CS2)); // GDEM1085T51 1360x480, JD79686AB, (FPC8617)
//GxEPD2_BW < GxEPD2_1330_GDEM133T91, GxEPD2_1330_GDEM133T91::HEIGHT / 2> display(GxEPD2_1330_GDEM133T91(SS, DC, RST, BUSY)); // GDEM133T91 960x680, SSD1677, (FPC-7701 REV.B)

// 3 Color
//GxEPD2_3C<GxEPD2_154_Z90c, GxEPD2_154_Z90c::HEIGHT> display(GxEPD2_154_Z90c(SS, DC, RST, BUSY)); // GDEH0154Z90 200x200, SSD1681
//GxEPD2_3C<GxEPD2_420c_Z21, GxEPD2_420c_Z21::HEIGHT> display(GxEPD2_420c_Z21(SS, DC, RST, BUSY)); // GDEQ042Z21 400x300, UC8276
//GxEPD2_3C<GxEPD2_420c_GDEY042Z98, GxEPD2_420c_GDEY042Z98::HEIGHT> display(GxEPD2_420c_GDEY042Z98(SS, DC, RST, BUSY)); // GDEY042Z98 400x300, SSD1683 (no inking)
//GxEPD2_3C<GxEPD2_583c_GDEQ0583Z31, GxEPD2_583c_GDEQ0583Z31::HEIGHT / 2> display(GxEPD2_583c_GDEQ0583Z31(SS, DC, RST, BUSY)); // GDEQ0583Z31 648x480, UC8179C
//GxEPD2_3C<GxEPD2_750c_Z08, GxEPD2_750c_Z08::HEIGHT> display(GxEPD2_750c_Z08(SS, DC, RST, BUSY)); // GDEW075Z08 800x480, GD7965
//GxEPD2_3C<GxEPD2_1160c_GDEY116Z91, GxEPD2_1160c_GDEY116Z91::HEIGHT / 2> display(GxEPD2_1160c_GDEY116Z91(SS, DC, RST, BUSY)); // GDEY116Z91 960x640, SSD1677
//GxEPD2_3C<GxEPD2_1330c_GDEM133Z91, GxEPD2_1330c_GDEM133Z91::HEIGHT / 4> display(GxEPD2_1330c_GDEM133Z91(SS, DC, RST, BUSY)); // GDEM133Z91 960x680, SSD1677
//GxEPD2_3C<GxEPD2_1248c, GxEPD2_1248c::HEIGHT / 4> display(GxEPD2_1248c(/*sck=*/ 12, /*miso=*/ -1, /*mosi=*/ 11, /*cs_m1=*/ 10, /*cs_s1=*/ 18, /*cs_m2=*/ 48, /*cs_s2=*/ 41, /*dc1=*/ 46, /*dc2=*/ 45, /*rst1=*/ 3, /*rst2=*/ 39, /*busy_m1=*/ 8, /*busy_s1=*/ 17, /*busy_m2=*/ 40, /*busy_s2=*/ 16)); // GDEY1248Z51 - 3C, 1304x984px, 12.48"
// 4 Color
//GxEPD2_4C<GxEPD2_154c_GDEM0154F51H, GxEPD2_154c_GDEM0154F51H::HEIGHT> display(GxEPD2_154c_GDEM0154F51H(SS, DC, RST, BUSY)); // GDEM0154F51H 200x200, JD79660 (FPC-8101) / GDEM0154F61H, SSD2681
//GxEPD2_4C<GxEPD2_154c_GDEM0154F51H, GxEPD2_154c_GDEM0154F51H::HEIGHT> display(GxEPD2_154c_GDEM0154F51H(SS, DC, RST, BUSY)); // GDEM0154F51H 200x200, JD79660 (FPC-8101)
//GxEPD2_4C<GxEPD2_213c_GDEY0213F51, GxEPD2_213c_GDEY0213F51::HEIGHT> display(GxEPD2_213c_GDEY0213F51(SS, DC, RST, BUSY)); // GDEY0213F51 122x250, JD79661 (FPC-A002 20.04.08)
//GxEPD2_4C<GxEPD2_290c_GDEY029F51H, GxEPD2_290c_GDEY029F51H::HEIGHT> display(GxEPD2_290c_GDEY029F51H(SS, DC, RST, BUSY)); // GDEY029F51H 168x384, JD79667 (FPC-H004 22.03.24)
//GxEPD2_4C<GxEPD2_420c_GDEY0420F51, GxEPD2_420c_GDEY0420F51::HEIGHT> display(GxEPD2_420c_GDEY0420F51(SS, DC, RST, BUSY)); // GDEY0420F51 400x300, HX8717 (no inking) / GDEM042F86, SSD2683ZA
//GxEPD2_4C<GxEPD2_750c_GDEM075F52, GxEPD2_750c_GDEM075F52::HEIGHT / 2> display(GxEPD2_750c_GDEM075F52(SS, DC, RST, BUSY)); // GDEM075F52 800x480, JD79665AA (FPC-8619) / GDEM075F53
//GxEPD2_4C<GxEPD2_1160c_GDEY116F51, GxEPD2_1160c_GDEY116F51::HEIGHT / 2> display(GxEPD2_1160c_GDEY116F51(SS, DC, RST, BUSY)); // GDEY116F51 960x640, SSD2677, (FPC-K012 23.09.27)

// 7 Color
//GxEPD2_7C < GxEPD2_565c_GDEP0565D90, GxEPD2_565c_GDEP0565D90::HEIGHT / 2 > display(GxEPD2_565c_GDEP0565D90(SS, DC, RST, BUSY)); // DIP: 1-ON, 2-OFF: GDEP0565D90 600x448 7-color (E219454, AB1024-EGA AC0750TC1)

/*  ------------------------------------------------------------------------------------------------- */
// Note: all supported ePapers you can find on https://github.com/ZinggJM/GxEPD2

void setup() {
  Serial.begin(115200);
  pinMode(POWER, OUTPUT); 
  digitalWrite(POWER, HIGH); // enable power supply for ePaper and uSup
  delay(500);

  display.init(); // inicializace
  display.fillScreen(GxEPD_WHITE);  // white background
  display.display(false); // update 

  delay(100);
  digitalWrite(POWER, LOW); // disable power supply for ePaper

  // deep sleep mode
  esp_sleep_enable_timer_wakeup(300 * 1000000);
  delay(200);
  esp_deep_sleep_start();
}

void loop() {

}

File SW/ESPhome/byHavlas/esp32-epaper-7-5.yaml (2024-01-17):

###################
#
#
# e-paper: GDEY075T7 7.5" 800x480
#
# case by IKEA
# HomeAssistant
# I2C
# ENABLE voltage for ePaper and I2C sensor - GPIO2 (HIGH - turn on, LOW - turn off)
#
# Made by (c) Lukas Havlas 2024
# Made by (c) laskakit.cz 2023
#
###################

#######
####### Radar sensor "ld2410" je zatím nefunkční, z definice vhodné odstranit
#######

substitutions:
  board_name: "ESP32-D0WD LaskaKit"

  gpio_display_clk: GPIO18
  gpio_display_mosi: GPIO23

  gpio_display_cs: GPIO5
  gpio_display_dc: GPIO17
  gpio_display_busy: GPIO4
  gpio_display_reset: GPIO16
  
  gpio_i2c_sda: GPIO21
  gpio_i2c_scl: GPIO22

  set_time_refresh: "60s"                                                   # refres time for E-ink - 300=5min production
  set_ha_entity_temp_outside:     sensor.solar_sht3_temperature_2            # name of entity for outside temperature
  set_ha_entity_temp_bathroom:    sensor.sdsio6_temp_apartman_koupel         # temp entity for bathroom
  set_ha_entity_temp_bedroom:     sensor.sdsio6_temp_apartman_loznice_zapad  # temp entity for bedroom
  set_ha_entity_temp_livingroom:  sensor.zb_apartman_air_quality_temperature # temp entity for livingroom

# Global variables for detecting if the display needs to be refreshed.
globals:
  - id: data_updated
    type: bool
    restore_value: no
    initial_value: 'false'

  - id: cpu_speed
    type: int
    restore_value: no
    initial_value: "0"

esphome:
  name: esp32-epaper-7
  friendly_name: esp32-epaper-7
  comment: E-ink 7.5" Apartmán v kuchyni meteo
  on_boot:
    priority: -100 #1000 #pokud je priority 1000 HTTP request neprobehne
    then:
      - lambda: |-  #pin 2 řídí napájení E-INK
          id(cpu_speed) = ESP.getCpuFreqMHz();
          pinMode(2, OUTPUT);
          digitalWrite(2, HIGH);
          delay(100);

esp32:
  board: nodemcu-32s
  #framework:
    #type: arduino

# Enable logging
logger:
  level: NONE
  #baud_rate: 0

# Enable Home Assistant API
api:
  encryption:
    key: "****************"

ota:
  password: "******************"

wifi:
  ssid: !secret wifi_ssid
  password: !secret wifi_password

  # Enable fallback hotspot (captive portal) in case wifi connection fails
  #ap:
   # ssid: "Esp32-Epaper-7-5"
    #password: "ueQ2w876vZfZXS"

captive_portal:

ld2410:
  id: ld2410_radar

uart:
  tx_pin: GPIO1
  rx_pin: GPIO3
  baud_rate: 256000
  parity: NONE
  stop_bits: 1

i2c:
  sda: $gpio_i2c_sda
  scl: $gpio_i2c_scl
  scan: false #uspora baterie default true

spi:
  clk_pin: $gpio_display_clk
  mosi_pin: $gpio_display_mosi

time:
  - platform: homeassistant
    id: time_homeassistant

output:
  - platform: gpio
    pin: GPIO2
    id: gpio_2


#Configuration entities
number:
  - platform: ld2410
    timeout:
      name: Radar Timeout
    max_move_distance_gate:
      name: Radar Max Move Distance
    max_still_distance_gate:
      name: Radar Max Still Distance
    g0:
      move_threshold:
        name: g0 move threshold
      still_threshold:
        name: g0 still threshold
    g1:
      move_threshold:
        name: g1 move threshold
      still_threshold:
        name: g1 still threshold
    g2:
      move_threshold:
        name: g2 move threshold
      still_threshold:
        name: g2 still threshold
    g3:
      move_threshold:
        name: g3 move threshold
      still_threshold:
        name: g3 still threshold
    g4:
      move_threshold:
        name: g4 move threshold
      still_threshold:
        name: g4 still threshold
    g5:
      move_threshold:
        name: g5 move threshold
      still_threshold:
        name: g5 still threshold
    g6:
      move_threshold:
        name: g6 move threshold
      still_threshold:
        name: g6 still threshold
    g7:
      move_threshold:
        name: g7 move threshold
      still_threshold:
        name: g7 still threshold
    g8:
      move_threshold:
        name: g8 move threshold
      still_threshold:
        name: g8 still threshold
  # Setting ending of zone 1 occupancy
  - platform: template
    name: "Radar End Zone 1"
    id: radar_z1_end
    device_class: distance
    min_value: 0
    max_value: 600
    step: 1
    mode: box
    update_interval: never
    optimistic: true
    restore_value: true
    initial_value: 10
    icon: "mdi:arrow-collapse-right"
    entity_category: CONFIG

  # Setting ending of zone 2 occupancy
  - platform: template
    name: "Radar End Zone 2"
    id: radar_z2_end
    device_class: distance
    min_value: 0
    max_value: 600
    step: 1
    mode: box
    update_interval: never
    optimistic: true
    restore_value: true
    initial_value: 36
    icon: "mdi:arrow-collapse-right"
    entity_category: CONFIG
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

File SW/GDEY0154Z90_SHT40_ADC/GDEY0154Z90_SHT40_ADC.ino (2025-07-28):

/*
* Example code shows values from SHT40 (temperature/humidity), battery voltage on eInk/ePaper display
*
* Compile as ESP32 dev module
* ESPink - ESP32 board for ePaper: https://www.laskakit.cz/laskakit-espink-esp32-e-paper-pcb-antenna/
* SHT40 (https://www.laskakit.cz/laskakit-sht40-senzor-teploty-a-vlhkosti-vzduchu/) is connected through uSup connector 
*
*
* Libraries:
* SHT40: https://github.com/adafruit/Adafruit_SHT4X
* EPD library: https://github.com/ZinggJM/GxEPD2
*
* made by laskakit (c) 2025
*/
 
#include <WiFi.h>
#include <GxEPD2_BW.h>
#include <GxEPD2_3C.h>
#include <GxEPD2_4C.h>
#include "SPI.h"
#include "Adafruit_SHT4x.h"
#include "OpenSansSB_12px.h"
#include "OpenSansSB_50px.h"
 
//#define ESPink_V2     //for version v2.6 and earlier
#define ESPink_V3     //for version v3.0 and above

#ifdef ESPink_V2
  //MOSI/SDI    23
  //CLK/SCK     18
  //SS/CS       5
  #define DC    17 
  #define RST   16  
  #define BUSY  4 
  #define POWER 2
  #define BAT   34

#else ESPink_V3
  //MOSI/SDI    11
  //CLK/SCK     12
  //SS/CS       10
  #define DC    48 
  #define RST   45  
  #define BUSY  38 
  #define POWER 47
  #define SDA   42
  #define SCL   2
  #define BAT   9
#endif

//GxEPD2_BW<GxEPD2_426_GDEQ0426T82, GxEPD2_426_GDEQ0426T82::HEIGHT> display(GxEPD2_426_GDEQ0426T82(SS, DC, RST, BUSY)); // GDEQ0426T82 480x800, SSD1677 (P426010-MF1-A)
//GxEPD2_4C<GxEPD2_290c_GDEY029F51H, GxEPD2_290c_GDEY029F51H::HEIGHT> display(GxEPD2_290c_GDEY029F51H(SS, DC, RST, BUSY)); // GDEY029F51H 168x384, JD79667 (FPC-H004 22.03.24)
GxEPD2_3C<GxEPD2_154_Z90c, GxEPD2_154_Z90c::HEIGHT> display(GxEPD2_154_Z90c(SS, DC, RST, BUSY)); // GDEH0154Z90 200x200, SSD1681
//GxEPD2_BW<GxEPD2_750_T7, GxEPD2_750_T7::HEIGHT> display(GxEPD2_750_T7(SS, DC, RST, BUSY)); // 7.5" b/w 800x480

// SHT40
Adafruit_SHT4x sht4 = Adafruit_SHT4x();

// ADC
float vBat = 0.0;
 
void setup() {
  Serial.begin(115200);
  pinMode(POWER, OUTPUT); 
  digitalWrite(POWER, HIGH); // enable power supply for ePaper and uSup
  delay(500);

  // read ADC and calculate the voltage
  vBat = analogReadMilliVolts(BAT) * 1.769 / 1000; // the ratio of divider, R2=1.3M; R1=1M


  /*----------- SHT40 -----------*/
  Wire.begin(SDA,SCL);
  if (! sht4.begin()) 
  {
    Serial.println("SHT4x not found");
    Serial.println("Check connection");
    while (1) delay(1);
  }

  sht4.setPrecision(SHT4X_HIGH_PRECISION); // the higest resolution
  sht4.setHeater(SHT4X_NO_HEATER); // no heater

  sensors_event_t humidity, temperature; // variable for humidity and temperature
  sht4.getEvent(&humidity, &temperature); // read value

  Serial.print("Temperature: "); Serial.print(temperature.temperature); Serial.println(" degrees C");
  Serial.print("Humidity: "); Serial.print(humidity.relative_humidity); Serial.println("% rH");

  display.init(); // inicializace

  display.setRotation(3);
  display.fillScreen(GxEPD_WHITE);  // white background
  display.setTextColor(GxEPD_BLACK);  // black font

  display.setCursor(/*x*/5, /*y*/50); // set cursor
  display.setFont(&OpenSansSB_50px); // font
  display.print(String(temperature.temperature, 1)); 
  display.print("  ");
  display.print(String(humidity.relative_humidity, 0)); 

  display.setFont(&OpenSansSB_12px); // font
  display.setCursor(/*x*/30, /*y*/70); // set cursor
  display.println(" degC");
  display.setCursor(/*x*/150, /*y*/70); // set cursor
  display.println(" % Rh");

  display.setCursor(/*x*/160, /*y*/100); // set cursor
  display.print(vBat);
  display.print(" V");

  display.display(false); // update 
  delay(100);
  digitalWrite(POWER, LOW); // disable power supply for ePaper

  // deep sleep mode
  esp_sleep_enable_timer_wakeup(300 * 1000000);
  delay(200);
  esp_deep_sleep_start();
}

void loop() {}

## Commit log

2021-10-28 mistake fixed
    [ESPink_top_bom.csv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]
2022-04-27 all new design
    [ESPink_top_bom.csv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]
2022-06-30 new design, data and SW
    [ESPink_top_bom.csv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]
2022-08-01 new version, see version.md
    [ESPink_top_bom.csv]
2022-10-10 new data
    [E-paper-adapter_top_bom.csv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]
2023-02-10 new ver
    [ESPink_top_bom.csv, ESPink_v2_top_bom.csv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]
2023-03-15 new test version
    [ESPink_v2_top_bom.csv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]
2023-11-13 old data moved
    [E-paper-adapter_top_bom.csv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]
2023-12-23 same model, fixed compatibility
    [Bottom_cover.3mf, LaskaKit-Live-7-5_Bottom.3mf, LaskaKit-Live-7-5_Top_2Legs.3mf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]
2024-01-22 Battery connector issue fixed
    [LaskaKit-Live-7-5_Bottom.3mf, LaskaKit-Live-7-5_Top_2Legs.3mf]
2024-04-09 minor changes around display
    [LaskaKit-Live-7-5_Bottom.3mf]
2024-04-25 new test ver
    [ESPink_v3_0_top_bom.csv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]
2024-06-04 minor update
    [LaskaKit-Live-7-5_Bottom.3mf, LaskaKit-Live-7-5_Top_2Legs.3mf]
2024-08-18 "Fix ADC reading"
2024-10-24 New LaskaKit Live kit
    [LaskaKit-Live-5-83_Bottom.3mf, LaskaKit-Live-5-83_Top_1Leg.3mf]
2024-11-21 prepared also for new ESPink v3
    [LaskaKit-Live-7-5_Top_2Legs.3mf]
2024-11-21 Create ESPink_v2_6_top_bom - IPEX.csv
    [ESPink_v2_6_top_bom - IPEX.csv]
2024-11-29 Update ESPink_v2_6_top_bom - IPEX.csv
    [ESPink_v2_6_top_bom - IPEX.csv]
2024-12-05 flex cable issue fix
    [LaskaKit-Live-5-83_Bottom.3mf, LaskaKit-Live-5-83_Top_1Leg.3mf]
2025-01-30 NEW TEST DATA
    [E-paper-touch-adapter_top_bom.csv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]
2025-03-09 new connector
    [E-paper-touch-adapter_top_bom.csv]
2025-04-01 more space for bigger battery
    [LaskaKit-Live-10-2_Bottom.3mf]
2025-04-02 adapter moved
    [LaskaKit-Live-11-6_Bottom.3mf]
2025-05-05 update for 11.6 4 color
    [LaskaKit-Live-11-6_Bottom.3mf]
2025-07-28 cleaning, changing folders
    [E-paper-touch-adapter_top_bom.csv, ESPink_v3_3_top_bom.csv, inkAdapter-7x_v1_bom.csv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]
2025-07-28 folder changed
    [LaskaKit-Live-7-5_Bottom.3mf, LaskaKit-Live-7-5_Top_2Legs.3mf]
2025-07-28 for new espink v3-5
    [LaskaKit-Live-7-5_Bottom.3mf, LaskaKit-Live-7-5_Top_2Legs.3mf]
2025-07-29 logo changed to heart
    [LaskaKit-Live-10-2_Top_2Legs.3mf, LaskaKit-Live-5-65_Top_1Leg.3mf, LaskaKit-Live-5-83_Top_1Leg.3mf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]
2025-09-09 new test adapter
    [E-paper-touch-dip-adapter_bom.csv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]
2026-03-06 new silkscreen
2026-04-15 new ver for 6000mAh bat
    [LaskaKit-Live-7-5_Bottom_v2.1.3mf, LaskaKit-Live-7-5_Top_2Legs_v2.1.3mf]
2026-05-22 moved to https://github.com/LaskaKit/Live
    [LaskaKit-Live-10-2_Bottom.3mf, LaskaKit-Live-10-2_Top_2Legs.3mf, LaskaKit-Live-11-6_Bottom.3mf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]
